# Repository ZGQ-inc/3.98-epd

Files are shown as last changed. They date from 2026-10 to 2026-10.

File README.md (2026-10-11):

# 3.98" BWRY 墨水屏随身伴侣 · Open E-Badge & Ita-Bag

<p align="center">
  3.98英寸 4色墨水屏外壳与随身工牌矢量图
</p>

<p align="center">
  <b>无需局域网 Wi-Fi · 手机 Chrome 蓝牙直连 · 100% 离线 PWA · Cloudflare Pages 免费一键托管</b><br>
  专为 3.98 英寸四色电子墨水屏打造的随身工牌、电子名片、兽聚痛卡与智能留言板开源软硬件全栈解决方案。
</p>

<p align="center">
  <a href="https://deploy.workers.cloudflare.com/?url=https://github.com/ZGQ-inc/3.98-epd">Deploy to Cloudflare Pages</a>
  
  
  
  
</p>

---

## 🌟 项目亮点 (Highlights)

1. **彻底告别 Wi-Fi 局域网依赖 (Zero Wi-Fi Needed)**:
   - 随身携带在展会、地铁、办公室或户外时，无需路由器局域网。
   - 打开手机或电脑 Chrome / Edge 浏览器访问部署好的 PWA 网页，点击“连接蓝牙”即可通过 Web Bluetooth API 直接与 3.98" 墨水屏握手直推。
2. **免费静态托管于 Cloudflare Pages**:
   - 纯前端无服务器架构（HTML5 + Canvas + Pure JS + Service Worker）。
   - 零成本全球 CDN 极速分发与自动权威 HTTPS（满足 Chromium WebBLE API 强制安全上下文要求）。
3. **100% 离线 PWA 支持 (Offline PWA)**:
   - 首次访问后，Service Worker 会将点阵字库生成器、二维码引擎和 4色微粒抖动算法缓存在本地。
   - 即使断网、飞行模式或深处地下场馆，依然能秒速打开并向墨水屏推送。
4. **四大随身定制工坊 (4 Built-in Studios)**:
   - 📇 **智能工牌 / 电子名片 (Smart E-Badge)**: 极客黑客、商务简约、同人展会等高对比度大字模板，内置零依赖纯离线二维码生成器。
   - 🎒 **兽聚痛卡 / 角色挂件 (Anime Ita-Bag Charm)**: 配合外壳双挂绳孔，相册选图、自由缩放/旋转、4色微粒抖动还原，个性台词题字。
   - 📝 **随身便签 / 留言板 (Memo & Checklist)**: 超大字号待办清单，方框复选框，磁吸/挂绳一目了然。
   - 🎨 **4色像素手绘画板 (BWRY Paint Canvas)**: 黑/白/红/黄 4色调色盘，画笔、矩形、圆形、题字、橡皮与撤销功能。
5. **极客级 3D 打印三明治外壳设计 (Optimized Enclosure)**:
   - **三明治三层坚固架构**: 前盖 + 中框 + 后盖独立分层，8 颗 M2 热熔铜螺母高强度锁合（前盖 4 颗 + 中框 4 颗）。
   - **防脱落滑动按键推钮**: 外露手按长度 1.5mm，加厚 7.0mm，四边 45° 倒角，内部防脱咬合卡块卡死后盖限位槽，杜绝脱落丢失。
   - **双挂绳孔**: 屏幕 FPC 一侧居中打 2 个穿绳孔（孔径 1.5mm，孔距 6mm），并带内部穿绳导引沉槽。
   - **前后双 NFC 贴片槽**: 中框正中心 + 后盖屏幕排线侧半边居中，适配 **NTAG216** (25mm 直径) 888 字节大容量贴片。
   - **4 颗强力吸附磁铁**: 后盖内壁预留 4 个 N52 钕铁硼磁铁沉孔（直径 6.0mm），可直接吸附在金属痛包或冰箱表面。

---

## 🗂️ 规范项目目录结构 (Repository Layout)

```text
.
├── README.md               # 项目主说明文档 (功能概览 / 快速编译与刷机指引)
├── BOM.md                  # 详尽硬件物料选型、采购单价与硬核避坑总结 (单一事实来源)
├── LICENSE                 # MIT 开源授权协议
├── .gitignore              # Git 忽略规则 (过滤 target/、编译缓存及临时文件)
│
├── hardware/               # 硬件与 3D 打印外壳工程
│   ├── README.md           # 3D 打印参数推荐与三明治全套组装指导
│   ├── enclosure_vector_mockup.svg # 外壳 1:1 矢量设计展示图
│   ├── 3d_models/          # 即用型 3D 打印 STL 模型与 OpenSCAD 源码
│   │   ├── case_front.stl  # 前框 (正面 6.9mm 窄边框，M2 铜螺母预埋孔)
│   │   ├── case_middle.stl # 中框 (双挂绳孔 1.5mm，正面 25mm NFC 槽，双 Type-C，'O'/`|` 开关标识)
│   │   ├── case_back.stl   # 标准后盖 (FPC 侧居中 25mm NFC 槽，4 个磁铁沉孔，电池防挤压圆角)
│   │   ├── case_back_logo.stl # 定制后盖 (带 "Made by ZGQ Inc." 凹刻文字)
│   │   ├── switch_cap.stl  # 防脱滑动推钮 (外露 1.5mm，卡紧后盖限位槽，4 道防滑齿)
│   │   ├── acrylic_template.stl # 91.0×64.0×1.5mm 亚克力视窗 1:1 划线切割模板
│   │   └── epd_case.scad   # 完整的 OpenSCAD 参数化建模源码
│   ├── scripts/
│   │   └── build_epd_case.py # Python 3D 网格生成脚本 (纯数学算法 + Delaunay 三角剖分)
│   └── fpc_adapter/        # 24-Pin 0.8mm 转 0.5mm 45° 转接板历史归档工程
│
├── cf_pages/               # 部署至 Cloudflare Pages 的 100% 离线独立 PWA 控制端
│   ├── README.md           # Cloudflare Pages 部署说明
│   ├── index.html          # 单页应用 (包含工牌、痛卡、便签、手绘 4 大工坊与 WebBLE 驱动)
│   ├── manifest.json       # PWA 应用配置清单
│   ├── sw.js               # Service Worker 离线缓存引擎 (v2.9)
│   ├── icon-192.svg        # 192x192 矢量图标
│   └── icon-512.svg        # 512x512 高清矢量图标
│
├── firmware/               # 预编译纯净固件与刷机指南
│   ├── README.md           # 详细环境配置与烧录步骤
│   └── epd-firmware.bin    # 预编译好的 1.76MB 裸机启动镜像 (即刷即用)
│
├── src/                    # Rust ESP-IDF 嵌入式主固件源码
│   ├── main.rs             # 系统启动入口、低功耗管理、任务并发调度
│   ├── ble/                # BLE 5.0 GATT 服务定义、流式点阵直推与无刷新预设协议
│   ├── display/            # 2bpp 硬件显存、无闪烁局刷与汉字字库渲染引擎
│   ├── storage/            # 1.5MB SPIFFS 效果库存储管理与物理配额统计
│   ├── modes/              # 工牌、痛卡、时钟、天气与便签模式逻辑
│   ├── power/              # 电源管理、电池电压 ADC 采样与休眠控制
│   ├── web/                # 内嵌轻量级 HTTP Web 服务器与 REST API
│   └── wifi/               # Wi-Fi 局域网通信与 AP 自动配网
│
├── web_assets/             # 编译期内嵌至固件的本地 Web 控制台静态资源
│   ├── index.html          # 局域网控制台 (已支持一键自定义配置您的专属 PWA 网址)
│   ├── index.html.gz       # 极速传输的 Gzip 压缩包
│   └── pwa.html            # 设备内置备用 PWA 页面
│
├── Cargo.toml              # Rust 项目依赖声明 (已配置 strip 自动剥离符号)
├── partitions.csv          # ESP32-C3 4MB Flash 分区表 (2MB App + 1.5MB SPIFFS 效果库)
└── sdkconfig.defaults      # ESP-IDF 系统底层配置 (启用蓝牙射频共存与蓝牙 5.0)
```

---

## 📋 硬件物料清单 (BOM)

关于器件的具体选型背景（**20~25 元华为生态四色墨水屏手机壳尾货捡漏实录**、高压驱动电压避坑、**663032 750mAh 锂电池**选型、**三明治 8 颗 M2 铜螺母锁固**及 NTAG216 智能名片细节），请直接参阅独立的硬件物料清单文档：

👉 **[硬件物料选型与采购清单 (BOM.md)](BOM.md)**

---

## 💻 固件编译与刷机指引 (Compilation & Flashing)

本项目主固件基于 **Rust ESP-IDF** 体系打造，针对 **ESP32-C3 (RISC-V 32位架构)** 进行了极致汇编与内存优化。

### 1. 为什么未剥离的 ELF 文件会有 20MB+？
在 `target/.../release/` 下生成的 `epd-firmware` 文件是标准的 RISC-V ELF 格式，包含了大量的 **DWARF 调试符号表**（`.debug_info`、`.debug_line`、函数符号与源码行号映射等，用于 GDB/LLDB 断点调试）。  
我们已在 `Cargo.toml` 中配置了 `debug = 0` 与 `strip = true`：
```toml
[profile.release]
opt-level = "z"
lto = "fat"
panic = "abort"
debug = 0
strip = true
```
真正烧录进单片机 Flash 的纯二进制镜像（.bin 文件）仅为 **1,764,592 字节（约 1.68 MB）**，完全适配 ESP32-C3 4MB Flash 的 **2MB 固件分区**（占用率 84.14%）。

---

### 2. 编译环境准备 (Prerequisites)

1. **安装 Rust 工具链**:
   ```bash
   curl --proto '=https' --tlsv1.2 -sSf https://sh.rustup.rs | sh
   ```
2. **安装 ESP32-C3 RISC-V 交叉编译器与烧录工具**:
   ```bash
   cargo install espup
   espup install
   cargo install espflash
   ```
3. **加载 ESP 编译环境变量**:
   - **Windows PowerShell**:
     ```powershell
     . $HOME/export-esp.ps1
     ```
   - **Linux / macOS**:
     ```bash
     source ~/export-esp.sh
     ```

---

### 3. 一键编译与固件导出

在项目根目录下执行：
```bash
# 1. 编译 release 生产模式固件
cargo +esp build --release

# 2. 将 ELF 可执行文件剥离并保存为单片机纯二进制镜像 (.bin)
espflash save-image --chip esp32c3 target/riscv32imc-esp-espidf/release/epd-firmware firmware/epd-firmware.bin
```

---

### 4. 烧录到设备 (Flash to ESP32-C3)

将 ESP32-C3 SuperMini 通过 Type-C 数据线连接至电脑：

#### 方式一：使用 `espflash` 自动烧录（最推荐）
```bash
# 自动探测串口并烧录
espflash flash --release

# 或指定具体串口号（例如 Windows 上的 COM17，Linux 上的 /dev/ttyUSB0）
espflash flash --port COM17 --release
```

#### 方式二：免编译直接烧录预编译镜像 (.bin)
仓库已在 `firmware/epd-firmware.bin` 预先提供了最新编译好的裸机固件。您可以使用 Python 的 `esptool.py` 直接刷入：
```bash
esptool.py --chip esp32c3 -p <PORT> -b 460800 write_flash 0x20000 firmware/epd-firmware.bin
```

---

### 5. Flash 分区表规划 (Partitions Layout)

4MB Flash 布局严格按照 `partitions.csv` 划分：

| 分区名 | 类型 | 子类型 | 偏移地址 | 大小 | 作用说明 |
| :--- | :--- | :--- | :--- | :--- | :--- |
| `nvs` | data | nvs | `0x9000` | 24 KB | 存储 Wi-Fi 凭据、蓝牙名称与模式持久配置 |
| `phy_init` | data | phy | `0x11000` | 4 KB | 射频初始化与天线校准数据 |
| `factory` | app | factory | `0x20000` | 2048 KB (2.0 MB) | Rust ESP-IDF 主固件代码段 (当前占用约 84%) |
| `font` | data | 0x01 | `0x220000` | 288 KB | Flash MMU 零内存占用标准点阵中文字库 |
| `storage` | data | spiffs | `0x268000` | 1632 KB (~1.6 MB) | 单片机内置 SPIFFS 效果库 (真实物理存储) |

---

## 🚀 1 分钟一键部署至 Cloudflare Pages

1. Fork 本仓库到你自己的 GitHub 账号；
2. 登录 [Cloudflare Dashboard](https://dash.cloudflare.com/)，点击 **Workers & Pages** -> **Create application** -> **Pages** -> **Connect to Git**；
3. 选择该仓库，配置构建参数：
   - **Framework preset**: `None`
   - **Build command**: *(留空)*
   - **Build output directory**: `cf_pages`
4. 点击 **Save and Deploy**，30 秒后即可获得免费的全球 CDN HTTPS 域名（例如: `https://my-epd-badge.pages.dev`）！
5. 在手机或电脑 Chrome / Edge 浏览器打开该网址，点击“连接蓝牙”即可开箱即用。

---

## 📄 开源许可证 (License)

本项目采用 [MIT 许可证](LICENSE) 开源，欢迎自由构建、修改、二次开发与商业/非商业分享！

> 💡 **关于版权与署名说明**：  
> 版权声明中的 `ZGQ Inc.` 仅为作者个人昵称（Author Handle）。本项目全栈源代码、固件、前端 PWA 及相关硬件工程文件均遵循宽松的 **MIT 许可证** 开放授权，任何人均可在遵守并保留 MIT 许可证声明的前提下自由使用、修改与衍生开发。

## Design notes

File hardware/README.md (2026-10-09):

# 3D 打印外壳与硬件结构设计指南 (Hardware & Enclosure)

本目录包含 3.98 英寸四色电子墨水屏随身工牌 & 兽聚痛卡的全部 3D 打印外壳 STL 模型、OpenSCAD 参数化源码、Python 网格构建脚本以及 FPC 屏幕转接板工程。

---

## 📁 目录结构说明

```text
hardware/
├── BOM.md                  -> 详细元器件选型与物料采购清单
├── enclosure_vector_mockup.svg -> 外壳 1:1 矢量结构展示图
├── 3d_models/              -> 3D 打印即用型 STL 文件与 OpenSCAD 源码
│   ├── case_front.stl      -> 前框 (正面 6.9mm 窄边框，M2 铜螺母预埋孔)
│   ├── case_middle.stl     -> 中框主体 (FPC侧与开关对面底壁双向双挂绳孔 1.5mm，支持横屏/竖屏挂绳，正面 25mm NFC 槽，双 Type-C 开孔，开关滑轨与 'O'/`|` 标识)
│   ├── case_back.stl       -> 标准后盖 (FPC 侧居中 25mm NFC 槽，4 个磁铁沉孔，电池防挤压 R7 圆角)
│   ├── case_back_logo.stl  -> 定制后盖 (带 "Made by ZGQ Inc." 激光/成型凹刻文字)
│   ├── switch_cap.stl      -> 防脱落滑动按键推钮 (外露 1.5mm，防脱咬合卡爪，4 道防滑齿)
│   ├── acrylic_template.stl-> 91.0 × 64.0 × 1.5 mm 亚克力视窗 1:1 划线/切割辅助治具
│   └── epd_case.scad       -> 完整的 OpenSCAD 参数化建模源码
├── scripts/
│   └── build_epd_case.py   -> Python 3D 网格生成脚本 (纯数学算法 + Delaunay 三角剖分)
└── fpc_adapter/            -> 24-Pin 0.8mm 转 0.5mm 45° 转接板工程（已作废归档，现采用 OSHWHub flamj0 高压驱动板）
```

> ⚠️ **关于转接板作废归档说明**：  
> 原自制 45° FPC 转接排线工程仅完成物理引脚间距转换（0.8mm 转 0.5mm），而 3.98" 四色屏（`SE0398NZ07`）需要高达 +22V / -20V / +15V 物理驱动偏压，普通驱动板无法正常工作。因此自制转接板已作废归档，硬件推荐采用立创开源硬件平台 [@flamj0 的墨水屏 FPC 转接板](https://oshwhub.com/flamj0/mo-shui-ping-fpc-zhuan-jie-ban)。

---

## 🖨️ 3D 打印参数推荐

| 打印部件 | 推荐层高 | 填充率 | 支撑设置 | 推荐材料 | 打印建议与方向 |
| :--- | :---: | :---: | :---: | :---: | :--- |
| **`case_front.stl`** | 0.12 - 0.16 mm | 100% | 无需支撑 | PETG / PLA+ / 树脂 | 外表面朝下贴紧热床，使用纹理 PEI 板可获得磨砂质感 |
| **`case_middle.stl`**| 0.12 - 0.16 mm | 100% | 局部轻微树状支撑 | PETG / ABS / 树脂 | 底部朝下平放，Type-C 开孔处开启少量支撑即可 |
| **`case_back.stl`**  | 0.12 - 0.16 mm | 100% | 无需支撑 | PETG / PLA+ / 树脂 | 外背面朝下贴紧热床 |
| **`switch_cap.stl`** | 0.08 - 0.12 mm | 100% | 无需支撑 | PETG / 高韧性光敏树脂 | 竖直或侧放打印，确保拔销孔尺寸精确 |

---

## 🔧 装配步骤示意

1. **热熔螺母安装**:
   - 取 4 颗 M2 铜螺母（外径 3.2mm，高 3.0~3.5mm），使用电烙铁压头对准 `case_front.stl` 背面的 4 个定位孔，轻压热熔至与塑料表面平齐。
2. **安装保护视窗与墨水屏**:
   - 依据 `acrylic_template.stl` 切割好 91.0×64.0×1.5mm 的透明亚克力板，嵌入口框内；
   - 将 3.98" 墨水屏正面四周贴好 0.3mm 超薄双面胶，居中粘合在前框背面。
3. **中框组件安装**:
   - 将微型滑动开关卡入中框顶部开关位，同时将 3D 打印推钮 `switch_cap.stl` 套在开关手柄上；
   - 固定 ESP32-C3 SuperMini 与 TP4056 充电板，确保两个 Type-C 接口分别居中露出；
   - 焊接开关引脚（控制电池正极切断/导通），连接电池与主控电源轨。
4. **NFC 贴片与磁铁装配**:
   - 中框正面中心凹槽粘贴第 1 枚 NTAG216 NFC 贴片；
   - 后盖排线侧半边中心凹槽粘贴第 2 枚抗金属 NTAG216 NFC 贴片；
   - 后盖内侧 4 个沉孔内分别压入 4 颗 N52 强力磁铁（6.0×1.2mm），可用少量 UV 胶或瞬干胶固定。
5. **合盖紧固**:
   - 将后盖对齐中框，确保滑动推钮防脱卡块嵌入后盖限位槽内；
   - 从后盖正面旋入 4 颗 M2×8mm 沉头机械螺丝并锁紧。

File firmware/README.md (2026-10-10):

# 固件烧录与编译指南 (Firmware Compilation & Flashing Guide)

本固件基于 **Rust ESP-IDF** 体系打造，专为 **ESP32-C3** (RISC-V 32位架构) 设计，实现了 4色墨水屏硬件显存管理、Web Bluetooth (WebBLE) 蓝牙直推、Wi-Fi 局域网控制台与低功耗多模式共存。

---

## 🛠️ 编译环境配置 (Prerequisites)

1. **安装 Rust 工具链**:
   ```bash
   curl --proto '=https' --tlsv1.2 -sSf https://sh.rustup.rs | sh
   ```
2. **安装 ESP32-C3 RISC-V 交叉编译器与 espflash 工具**:
   ```bash
   cargo install espup
   espup install
   cargo install espflash
   ```
3. **加载 ESP 环境变量**:
   - **Windows PowerShell**:
     ```powershell
     . $HOME/export-esp.ps1
     ```
   - **Linux / macOS**:
     ```bash
     source ~/export-esp.sh
     ```

---

## 📦 固件编译与剥离 (Build & Strip)

项目 `Cargo.toml` 已经内置了符号剥离配置（`debug = 0`, `strip = true`, `lto = "fat"`）：

```bash
# 1. 在项目根目录执行 release 编译
cargo +esp build --release

# 2. 将 ELF 可执行文件提取为纯净裸机固件镜像 (.bin)
espflash save-image --chip esp32c3 target/riscv32imc-esp-espidf/release/epd-firmware firmware/epd-firmware.bin
```

> **💡 ELF 与 BIN 的体积说明**:
> - `target/.../release/epd-firmware` 是未提取的 ELF 格式，早期包含 DWARF 调试符号时可达 20MB+（现经 `strip = true` 优化后约 3MB）；
> - 真正通过 `espflash save-image` 或 `espflash flash` 烧录进 ESP32-C3 Flash 的裸机二进制固件（`.bin`）仅为 **1,764,592 字节（约 1.68 MB）**，完全适配 2MB 固件分区。

---

## ⚡ 一键烧录到设备 (Flash)

### 方式一：使用 `espflash` 自动烧录 (最推荐)
将 ESP32-C3 SuperMini 通过 Type-C 数据线连接至电脑（设备管理器中查看端口号，例如 Windows 上的 `COMx` 或 Linux 上的 `/dev/ttyUSB0`）：
```bash
# 自动检测串口并烧录
espflash flash --release

# 或指定具体串口（请将 COM17 替换为你的实际串口号）
espflash flash --port COM17 --release
```

### 方式二：免编译直接使用 `esptool.py` 刷入预打包固件
本目录已预先提供构建好的 `epd-firmware.bin` (1.76MB)：
```bash
esptool.py --chip esp32c3 -p <PORT> -b 460800 write_flash 0x20000 firmware/epd-firmware.bin
```

---

## 🧭 Flash 分区表规划 (Partitions Table)

4MB Flash 布局严格遵循项目根目录下的 `partitions.csv`：

| 分区名 (Name) | 类型 (Type) | 子类型 (SubType) | 偏移地址 (Offset) | 分区大小 (Size) | 作用说明 |
| :--- | :--- | :--- | :--- | :--- | :--- |
| `nvs` | data | nvs | `0x9000` | 24 KB (`0x6000`) | 存储 Wi-Fi 凭据、蓝牙设备名与模式配置 |
| `phy_init` | data | phy | `0x11000` | 4 KB (`0x1000`) | 射频初始化校准数据 |
| `factory` | app | factory | `0x20000` | 2048 KB (`0x200000`, 2.0MB) | Rust ESP-IDF 完整主固件镜像 (当前约占 84%) |
| `font` | data | 0x01 | `0x220000` | 288 KB (`0x48000`) | Flash MMU 零内存占用标准点阵中文字库 |
| `storage` | data | spiffs | `0x268000` | 1632 KB (`0x198000`, ~1.6MB)| 单片机内置 SPIFFS 效果库 (真实物理存储) |

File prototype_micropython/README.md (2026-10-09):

# 3.98" BWRY 墨水屏 MicroPython 原型验证 Demo (Prototype)

本目录包含了项目初期用于验证 3.98 英寸四色墨水屏（SSD1683 控制器，768×552 分辨率）硬件管脚、SPI 通信、微粒抖动算法与刷新波形的核心 MicroPython 驱动与测试例程。

---

## 📁 文件清单

- **`epd3in98.py`**:
  - 3.98 英寸 4 色电子墨水屏 (BWRY) 的 MicroPython 底层驱动库。
  - 封装了 SSD1683 的 SPI 初始化序列、寄存器控制、2bpp (2-bit per pixel) 显存管理、全刷/局刷控制及低功耗休眠指令。
- **`demo.py`**:
  - 基础硬件与图像测试脚本。
  - 演示了四色基础几何图形绘制、文字排版题字以及将 RAW 二进制图像推送至墨水屏物理刷新的完整流程。
- **`convert_image.py`**:
  - PC 端图片格式转换与 4 色 Floyd-Steinberg 误差扩散抖动算法脚本。
  - 可将任意格式的 JPG/PNG 图片缩放为 768×552 并转换为黑/白/红/黄 4 色 2bpp 原始显存二进制文件（`.raw`）。
- **`avatar.raw`**:
  - 预生成的 768×552 4 色测试图片二进制数据样本（可直接由 `demo.py` 读取刷屏）。
- **`SE0398NZ07_MicroPython.zip`**:
  - 原始完整备份压缩包（含厂家技术参考、引脚对照图与初期测试工程）。

---

## 🚀 快速测试方法 (MicroPython)

1. 在开发板（如 ESP32-C3）上刷入标准 MicroPython 固件；
2. 使用 Thonny IDE 或 `mpremote` / `ampy` 将 `epd3in98.py`、`demo.py` 和 `avatar.raw` 上传到开发板根目录；
3. 根据硬件接线修改 `demo.py` 中的 GPIO 引脚分配（SCK, MOSI, CS, DC, RST, BUSY）；
4. 运行 `demo.py`，墨水屏即可完成物理颗粒沉淀全彩刷新。

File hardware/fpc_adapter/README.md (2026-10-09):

# 【作废存档 · ARCHIVED】24-Pin 0.8mm 焊接 转 0.5mm 45° 仿形转接排线工程

> ⚠️ **作废与归档声明 (DEPRECATION & ARCHIVE NOTICE)**：  
> 本目录下的 24-Pin 0.8mm 转 0.5mm 45° 仿形转接排线工程已正式**作废并封存归档**。
>
> **原因说明**：  
> 如原型文章（[25元捡漏3.98寸四色墨水屏！MicroPython 驱动与 FPC 转接避坑实录 · ID: e398nz](https://zgqinc.gq/posts/e398nz/)）中所述，3.98 英寸四色墨水屏（`SE0398NZ07-FNG-A0`）采用高密度 BWRY 彩色电泳微胶囊，其翻转电场需要极高的物理高压驱动（`VGH` +22V / `VGL` -20V / `VSH` +15V）。市售普通通用 24P 黑白屏驱动板由于升压回路电感与元器件耐压不足，无法拉升至所需阈值，会导致 BUSY 信号永久忙死锁或刷屏缺色淡色。
>
> **现行推荐替代方案**：  
> 本项目现已全面改用立创开源硬件平台（OSHWHub）成熟开源项目：  
> **[墨水屏 FPC 转接板 (OSHWHub @flamj0)](https://oshwhub.com/flamj0/mo-shui-ping-fpc-zhuan-jie-ban)**  
> 该转接板自带足额储能电感与高耐压升压驱动回路，可直接将 3.98" 裸屏安全稳定连接至主控。
>
> 本目录完整保留历史 KiCad 版图源码、Gerber 打样压缩包与 EasyEDA 导入工程，仅供技术研究、引脚对照与历史归档参考，**新制作请勿再打样此转接板**。

---

## 🛠️ 历史设计特性归档 (Historical Design Archive)

1. **45° 仿形外形 (Contour Outline)**：
   - 移除原先直角两侧多余无走线的死基材，外框完全沿 45° 扇出走线平滑收拢，轻量美观。
2. **插舌与金手指精密适配 (J_ZIF)**：
   - 插舌宽度严格控制在 **12.50 mm**，前端带有 **0.3 mm × 45° 导向倒角**，插拔顺畅不卡壳。
   - 金手指长度加长至 **3.20 mm**（原 1.8mm），确保在任意 0.5mm ZIF 翻盖插座中弹片均能可靠接触。
   - 采用整排开窗（Gang Mask Opening，无开窗桥），彻底解决 0.2mm 窄间隙覆盖膜起翘与毛刺问题。
3. **消除冗余底层铜皮**：
   - 完全清理了原先底层未连接走线的 24 个冗余焊盘，避免热应力翘曲及寄生耦合。
4. **PI 补强层定义 (User.1 / Stiffener)**：
   - **插舌背面**：`12.50 mm × 3.50 mm` PI 补强片（建议选择 0.15~0.20mm PI，加上 0.11mm 板厚总计约 0.3mm，完美卡紧）。
   - **焊接端背面**：`20.40 mm × 3.50 mm` 耐热 PI 补强片，方便手工电烙铁焊接与支撑。
5. **极客风格丝印 (SilkScreen)**：
   - 正面标注 `[ ZGQ Inc. ]`、`EPD 24P: SOLDER > ZIF`、`3.98" SCREEN ADAPTER`。
   - 醒目标注两端 `1`、`24` 脚位与常用引脚功能标识，且全部严格位于板框安全间距内。
6. **嘉立创双面 FPC 0元体验券原生兼容**：
   - 导出文件包含完整的顶层与底层层叠定义，嘉立创自动识别为双面板，完美享受官方“双面 FPC 免费券（含 1 种 PI 补强免单）”。

---

## 📐 24-Pin 引脚网络映射参考表 (1:1 直连)

| Pin # | 引脚名称 | 功能说明 | 屏幕端 (0.8mm) | 驱动板端 (0.5mm) |
| :---: | :---: | :---: | :---: | :---: |
| **1** | GDR | N沟道MOS驱动 (Boost Gate) | Pad 1 | Pin 1 |
| **2** | RESE | 电流采样反馈电阻端 | Pad 2 | Pin 2 |
| **3** | VSH2 | 升压正高压 2 (约 +15V) | Pad 3 | Pin 3 |
| **4** | NC (PREVGH) | 预留升压测试脚 (内部悬空) | Pad 4 | Pin 4 |
| **5** | NC (PREVGL) | 预留升压测试脚 (内部悬空) | Pad 5 | Pin 5 |
| **6** | NC (TSCL) | 触控时钟 (本屏无触控) | Pad 6 | Pin 6 |
| **7** | NC (TSDA) | 触控数据 (本屏无触控) | Pad 7 | Pin 7 |
| **8** | BS | 通讯模式选择 (拉低默认 SPI) | Pad 8 | Pin 8 |
| **9** | BUSY | 墨水屏忙状态指示 (低电平忙) | Pad 9 | Pin 9 |
| **10** | RST | 硬件复位信号 (低电平复位) | Pad 10 | Pin 10 |
| **11** | DC | 数据/命令控制脚 (高:数据, 低:命令)| Pad 11 | Pin 11 |
| **12** | CS | 片选信号 (低电平有效) | Pad 12 | Pin 12 |
| **13** | SCL / CLK | SPI 同步时钟信号 | Pad 13 | Pin 13 |
| **14** | SDA / DIN | SPI 串行数据输入信号 | Pad 14 | Pin 14 |
| **15** | VDDIO | 逻辑供电 (3.3V) | Pad 15 | Pin 15 |
| **16** | VCI / VDD | 模拟主供电 (3.3V) | Pad 16 | Pin 16 |
| **17** | VSS / GND | 系统参考地 | Pad 17 | Pin 17 |
| **18** | VDD | 核心稳压电容引脚 | Pad 18 | Pin 18 |
| **19** | VPP | OTP 烧录高压供电 (悬空/接电容) | Pad 19 | Pin 19 |
| **20** | VCOM | 屏幕公共极驱动电压 | Pad 20 | Pin 20 |
| **21** | VGL | 负偏压驱动电压 (约 -20V) | Pad 21 | Pin 21 |
| **22** | VGH | 正偏压驱动电压 (约 +22V) | Pad 22 | Pin 22 |
| **23** | VSL | 负驱动参考电压 | Pad 23 | Pin 23 |
| **24** | VSH1 | 正驱动参考电压 1 (约 +15V) | Pad 24 | Pin 24 |

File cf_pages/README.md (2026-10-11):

# 3.98" BWRY E-Paper Open Smart Badge & Ita-Bag (开源墨水屏随身伴侣)

> **Zero Wi-Fi Required** · **100% Client-Side Offline PWA** · **Web Bluetooth (WebBLE) Direct Drive** · **One-Click Deploy to Cloudflare Pages**

Deploy to Cloudflare Pages (https://deploy.workers.cloudflare.com/?url=https://github.com/ZGQ-inc/3.98-epd)




---

## 🌟 项目亮点 (Highlights)

1. **彻底告别 Wi-Fi 依赖 (No Wi-Fi Needed)**:
   - 随身携带在兽聚、地铁、办公室或野外时，无需路由器局域网。
   - 打开手机或电脑 Chrome / Edge 浏览器访问本 PWA 网页，点击“连接蓝牙”即可通过 Web Bluetooth API 直接与 3.98" 墨水屏握手通信。
2. **免费静态托管于 Cloudflare Pages**:
   - 纯前端静态架构（HTML5 + Canvas + Pure JS + Service Worker）。
   - 无需任何后端服务器、Docker 或数据库，零成本全球 CDN 极速分发与自动 HTTPS（WebBLE API 强制要求 HTTPS）。
3. **100% 离线 PWA 支持 (Offline PWA)**:
   - 首次访问后，Service Worker 会将所有点阵字库生成器、RFC-Compliant 二维码引擎和 4色抖动算法缓存在本地。
   - 即使断网、飞行模式或深处兽聚地下场馆，依然能秒速打开并向墨水屏推送。
4. **四大随身定制工坊 (4 Built-in Studios)**:
   - 📇 **智能工牌 / 电子名片定制 (Smart E-Badge)**: 极客黑客、商务简约、兽聚同人、展会工作证 4 套高对比度大字模板，内置零依赖纯离线二维码生成器。
   - 🎒 **兽聚痛卡 / 角色挂件 (Anime Ita-Bag Charm)**: 配合 3D 打印外壳的双挂绳孔设计，相册选图、自由缩放/旋转、4色微粒抖动还原，个性台词题字。
   - 📝 **随身便签 / 冰箱贴 (Memo & Checklist)**: 32px 超大字号待办清单，方框复选框，磁吸/挂绳一目了然。
   - 🎨 **4色像素手绘画板 (BWRY Paint Canvas)**: 黑/白/红/黄 4色调色盘，画笔、矩形、圆形、题字、橡皮与撤销功能。
5. **多设备记忆与切换 (Multi-Device Support)**:
   - 自动记忆多个已配对的墨水屏胸牌与痛包挂饰，支持自定义备注别名（例如“工作胸牌”、“痛包立绘挂饰”、“厨房留言板”），一键重连。
6. **蓝牙隔空配网 (BLE Air Provisioning)**:
   - 如果用户后续需要连接 Wi-Fi（例如用于 Home Assistant 联动、天气看板、NTP 时钟），无需连接难用的 AP 热点，直接在蓝牙控制台中输入 SSID 和密码一键隔空写入。

---

## 🚀 1分钟部署到 Cloudflare Pages (Deploy Guide)

### 方式一：一键自动部署 (Recommended)
1. 将本仓库 `cf_pages/` 目录推送到你自己的 GitHub 仓库。
2. 登录 [Cloudflare Dashboard](https://dash.cloudflare.com/)，进入 **Workers & Pages** -> **Create application** -> **Pages** -> **Connect to Git**。
3. 选择你的仓库，配置如下：
   - **Framework preset**: `None`
   - **Build command**: *(留空)*
   - **Build output directory**: `.` (或填写 `cf_pages`)
4. 点击 **Save and Deploy**，30 秒内即可获得专属于你的全球 HTTPS 地址（如 `https://my-epd-badge.pages.dev`）！

### 方式二：Cloudflare Wrangler CLI 部署
```bash
npm install -g wrangler
cd cf_pages
wrangler pages deploy . --project-name=epd-badge
```

---

## 📱 手机与电脑蓝牙直连要求 (Browser Compatibility)

| 平台 / 操作系统 | 推荐浏览器 | Web Bluetooth 支持情况 |
| :--- | :--- | :--- |
| **Android** | Google Chrome / Edge / Opera | ✅ 开箱即用 (原生支持 WebBLE) |
| **Windows / macOS** | Google Chrome / Microsoft Edge | ✅ 开箱即用 (需系统支持蓝牙 4.0+) |
| **Linux** | Google Chrome / Chromium | ✅ 需开启 `chrome://flags/#enable-web-bluetooth` |

---

## 📐 硬件规格参数 (Hardware Specifications)

- **显示面板**: 3.98 英寸超高清 4 色电子墨水屏 (BWRY: 黑/白/红/黄)
- **分辨率**: 768 × 552 像素 (1:1 点对点 2bpp 硬件显存，整屏 105,984 字节)
- **主控芯片**: ESP32-C3 SuperMini (RISC-V 160MHz, BLE 5.0 + Wi-Fi 802.11b/g/n)
- **刷新速度**: ~16 秒物理全色阶颗粒沉淀刷新，断电永久保持画面不耗电
- **结构设计**:
  - 外壳左上方配备 **双挂绳孔** (间距 6.0mm，孔径 1.5mm)，便于穿过挂绳作为胸牌或钥匙扣。
  - 内置 **前后双 NFC 贴片凹槽** (中框正中心 + 屏幕排线侧背面中心，直径 25.5mm)，可贴手机触碰感应标签。
  - 防脱落拨动开关推扭设计 (防掉防脱手感优化)。

---

## 📡 蓝牙 GATT 协议接口规范 (BLE Specification)

- **Service UUID**: `000000ff-0000-1000-8000-00805f9b34fb`
- **RX Characteristic (Write Without Response)**: `0000ff01-0000-1000-8000-00805f9b34fb`
  - 用于流式接收 2bpp 105,984 字节点阵（单包建议 240 字节）或 JSON/文本控制指令。
- **TX Characteristic (Notify / Read)**: `0000ff02-0000-1000-8000-00805f9b34fb`
  - 用于向网页回报墨水屏当前电量、刷新进度、IP 地址与状态信息。

### 控制指令速查：
- `refresh` : 触发墨水屏 16s 物理全刷新
- `mode:<mode_name>` : 切换预设场景（如 `demo`, `memo`, `fridge_board`, `weather` 等）
- `wireless:<mode>` : 切换射频模式（`auto`, `ble_only`, `wifi_only`, `dual`）
- `{"cmd":"wifi_setup","ssid":"...","pass":"..."}` : 隔空配置 Wi-Fi 路由器信息

---

## 📄 开源许可证 (License)

本项目采用 [MIT 许可证](https://github.com/ZGQ-inc/3.98-epd/blob/main/LICENSE) 开源。

> 💡 **关于版权与署名说明**：  
> `ZGQ Inc.` 仅为作者个人昵称（Author Handle）。本项目前端 PWA 代码、UI 及模型均以宽松的 MIT License 开放授权，任何人均可在遵守 MIT 协议的前提下自由学习、修改、二次开发与商业/非商业分享。

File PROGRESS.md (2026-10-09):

# EPD Smart Display Firmware (Rust) — 实施进度记录 (PROGRESS.md)

> 设备：ESP32-C3 SuperMini + 3.98" 4色墨水屏（SE0398NZ07-FNG-A0/A1，768×552，4色BWRY）  
> 目标端口：COM17 (4MB SPI Flash)  
> 当前版本：v2.0  
> 最新更新时间：2026-10-07 01:28

---

## 阶段推进状态总览

| 阶段 | 任务目标 | 状态 | 交付文件与技术要点 |
|---|---|---|---|
| **Phase 0** | 工具链探测、分区表规划与工程基建 | **已完成 (DONE)** | `partitions.csv`, `Cargo.toml`, `sdkconfig.defaults`, `.cargo/config.toml`, `build.rs` |
| **Phase 1** | 768×552 4色墨水屏底层驱动与显存渲染核 | **已完成 (DONE)** | `src/display/color.rs`, `src/display/framebuffer.rs`, `src/display/driver.rs`, `src/display/font.rs`, `src/display/mod.rs` |
| **Phase 2** | WiFi网络管理 (AP/STA/Captive Portal)、HTTPD服务与REST API | **已完成 (DONE)** | `src/wifi/mod.rs`, `src/wifi/captive.rs`, `src/web/mod.rs`, `src/web/api.rs`, `src/config/mod.rs` |
| **Phase 3** | 17 项全场景内容模式渲染引擎 | **已完成 (DONE)** | `src/modes/mod.rs` (Memo, Calendar, Weather, FridgeBoard, Countdown, Habit, LifeBar 等) |
| **Phase 4** | 调度器、休眠/心跳模式与 Home Assistant MQTT 集成 | **已完成 (DONE)** | `src/power/mod.rs`, `src/mqtt/mod.rs`, `src/scheduler/mod.rs` |
| **Phase 5** | Material Web 控制台与 Fabric.js Canvas 布局编辑器 | **已交付 (DONE)** | `web_assets/index.html`：768×552 自由拖拽画布排版 Studio 与全功能配置面板 |
| **Phase 6** | 系统联调、固件构建与实机全链路运行验证 | **已交付并通过实机验证 (PASSED & VERIFIED)** | Release 固件成功构建，已烧录至 COM17，SoftAP `EPD-Display-A00D` 现场广播正常，WebUI/DNS 就绪 |
| **Phase 7** | 内存/体积优化、断电智能免刷新与 WebUI 推送全闭环 | **全部完成并通过物理实机验证 (PASSED & VERIFIED)** | 可用堆内存提升至 75KB+；固件裁剪至 1.39MB；CRC32 断电状态记忆免闪烁；Web 端画布与模式切换全链路打通 |

---

## 详细里程碑记录

### [2026-10-07 01:12] Phase 0：基础工程与构建配置交付
1. 探测本地工具链：确认 `rustc +esp` (nightly), `espflash 4.6.0`, `ldproxy`, `libclang.dll` 完好就绪。
2. 验证 COM17 物理板载连接：成功识别 `esp32c3 (revision v0.4)`，4MB Flash，MAC `14:63:93:6e:a0:0c`。
3. 创建 4MB Flash 自定义分区表 `partitions.csv`（nvs, otadata, phy_init, ota_0 (1.5MB), ota_1 (1.5MB), storage/spiffs (896KB)）。
4. 创建 `sdkconfig.defaults`：配置 4MB Flash、USB-Serial/JTAG 默认控制台、WiFi SoftAP、mbedTLS 堆栈削减。
5. 配置 `.cargo/config.toml`：重定向构建产物到 `C:\esp_b\epd`（防 Windows 路径超长），配置 `rust-lld.exe` 主机链接器与 `xwin` 库路径。

### [2026-10-07 01:14] Phase 1：4色墨水屏驱动与 103.5KB 显存交付
1. **`src/display/color.rs`**：定义 SE0398NZ07 4 色枚举（BWRY: Black=00, White=01, Yellow=10, Red=11），实现 `embedded_graphics::pixelcolor::PixelColor`。
2. **`src/display/framebuffer.rs`**：显存移至编译期 `.bss` 静态区（`EPD_STATIC_BUFFER`），105,984 字节 / 103.5 KB，**0 字节动态堆开销**，彻底规避运行时内存碎片与 OOM；为 `BwryColor` 实现 `DrawTarget`；实现毫秒级快速单色清屏与 2-bit 点阵零开销 blit。
3. **`src/display/driver.rs`**：完整移植 A0/A1 物理交错扫描线地址映射（CMD `0x83` + `0x10`），配置 8MHz 硬件 SPI（SCK=4, MOSI=6, CS=7, DC=1, RST=2, BUSY=10），精准匹配 16 秒物理波形刷新与深度休眠序列。
4. **`src/display/font.rs`**：封装多规格等宽字体与文字居中排版工具。

### [2026-10-07 01:15] Phase 2：网络、配网与嵌入式 HTTPD 交付
1. **`src/config/mod.rs`**：NVS 键值对持久化引擎，使用 `get_blob` / `set_blob` 支持序列化/反序列化 WiFi 凭据、MQTT 与展示偏好。
2. **`src/wifi/captive.rs`**：在 UDP 53 端口自建轻量 DNS 重定向服务器，实现手机连上 SoftAP 自动弹出 Captive Portal 配网页面。
3. **`src/wifi/mod.rs`**：WiFi 状态机管理（未配网或连不上时自动开启 `EPD-Display-XXXXXX` AP，已配网自动连 STA），锁定 `heapless 0.9` 统一接口。
4. **`src/web/api.rs`**：REST API 数据结构（系统状态、WiFi 配网请求、统一响应体）。
5. **`src/web/mod.rs`**：基于 `EspHttpServer` 提供 REST 接口与内置自适应 Material Design 响应式控制台。
6. **`src/power/mod.rs`**：支持心跳省电模式与 RTC 定时 Deep Sleep。

### [2026-10-07 01:16] Phase 3 & Phase 4：17 种内容模式、MQTT 与调度引擎交付
1. **`src/modes/mod.rs`**：抽象 `DisplayMode` trait 与统一分发器，实现便签、日历、全维气象、冰箱贴布告板、倒计时、打卡热力图、人生进度条等 17 种场景模式。
2. **`src/mqtt/mod.rs`**：接入 Home Assistant 官方最新的 Device-Based MQTT Auto Discovery 规范，自动向 HA 注册电量传感器、刷新按钮与心跳休眠开关。
3. **`src/scheduler/mod.rs`**：多级后台定时调度器，协调气象轮询、午夜日历切换与心跳遥测。
4. **`src/main.rs`**：完整链路编排与外设启动。

### [2026-10-07 01:25] Phase 5：Web 控制台与 Fabric.js 768×552 Studio 交付
1. **`web_assets/index.html`**：实现基于 Fabric.js v6 的 768×552 物理点阵等比自由拖拽画布，支持文本、天气、日历、备忘等挂件自由排版与 4 色模拟。

### [2026-10-07 18:10] Hotspot WebUI 超时问题彻底根治与验证
1. **HTTP 协议报头优化**：
   - 为所有 HTTP 响应（包括主页 `/`、Captive Portal 302 重定向以及 `/api/*` REST 接口）严格注入 `Content-Length` 与 `Connection: close`。
   - 彻底解决了 HTTP/1.1 默认 Keep-Alive 模式下移动端与桌面端浏览器接收完数据后因缺少 EOF 标识而无限悬挂加载最终超时的严重问题。
2. **启动顺序调整**：
   - 将 `WebServer::start` 调整至 WiFi 启动后**立刻执行**（不再受耗时 16~40 秒的墨水屏全屏波形刷新阻塞），开机 1 秒内 HTTP 服务器即上线监听 80 端口。
3. **DNS Captive Portal RFC 规范兼容**：
   - 在 UDP 53 端口 DNS 回应中对 Question 边界做严格字节解析并清除 `ARCOUNT`，彻底解决各平台移动设备发送 EDNS0/OPT 附加段时 DNS 解析损坏被系统静默丢弃的问题。
### [2026-10-07 18:40] 基于成熟项目 mi-remote-esp32 完整重构强制门户（Captive Portal）与配网架构
1. **参考 mi-remote-esp32 成功实现重构**：
   - 采用同款经真机实测检验的 **「无网自动降级 AP + DNS 劫持强制弹窗 + 轻量 WebUI 提交 + NVS 持久化重启」** 架构。
   - `src/wifi/mod.rs`：显式调用 `wait_netif_up` 后，对 AP Netif 执行 `esp_netif_dhcps_stop` -> 绑定 `192.168.4.1` -> `esp_netif_dhcps_start` 完整 DHCP 生命周期，避免手机获取不到网关与 DNS。
   - `src/wifi/captive.rs`：精确实现 4KB 独立线程 UDP 53 DNS 欺骗响应，将所有 A 记录查询重定向至 `192.168.4.1`。
   - `src/web/mod.rs`：拦截系统专属探测路由（`/generate_204`、`/gen_204`、`/hotspot-detect.html`、`/ncsi.txt`、`/connecttest.txt` 等），统一直接下发 `web_assets/captive.html` 单页。使用 `Box::leak(Box::new(server))` 确保 HTTP 守护线程生命周期永久有效。
   - `src/wifi/mdns.rs`：新增基于局域网组播的 mDNS 响应器，连网后电脑或手机浏览器可直接通过 `http://epd-display.local` 免 IP 访问控制台。
### [2026-10-07 18:48] Wi-Fi 成功连网、C3 迷你中文点阵字库刷入与屏幕状态显示交付
1. **网络连接状态确认**：
   - 目标网络：`Home_WiFi`（已连入）
   - 路由器分配内网 IP：`192.168.1.xxx`
   - mDNS 本地域名：`http://epd-display.local/`
   - 串口日志实测证明 Wi-Fi 配网参数保存后自动重启并顺利上线。
   - 修复了此前在连网模式下根路径仍下发 Captive Portal 的问题，改为下发完整的 Material Web 控制台与 Fabric.js 画布 Studio。
2. **C3 迷你中文词库集成与 Flash 刷入**：
   - 针对 ESP32-C3 资源限制，整合开源 `HZK16`（7445 个标准中文字符）与 `ASC16`。
   - 自主构建 `font_c3.bin`（32字节文件头 + 128 ASCII 字模 + 7445 字符升序 Unicode 索引表 + 16×16 点阵字模全集），全库仅 263.7 KB。
   - 通过 `espflash write-bin 0x320000 font_c3.bin` 成功烧录至 Flash `storage` 分区。
   - 编写 `src/display/font.rs`，利用 ESP-IDF 硬件 MMU 机制（`esp_partition_mmap`）实现零 RAM 占用的瞬时字模索引与放大渲染。
3. **墨水屏配网全流程状态显示**：
   - 编写 `src/modes/provisioning.rs`：
     - **等待配网中**：红黄底横幅 + 卡片清晰展示热点名称 `EPD-Display-A00D`、IP `192.168.4.1` 及 4 步图文操作向导。
     - **配网成功**：高亮展示已连接 Wi-Fi 名称、分配到的局域网 IP 与 mDNS 域名，以及控制台访问指引。
     - **配网失败**：红底提示错误原因并引导重新配网。

### [2026-10-07 19:50] 内存与刷机包优化、智能断电判别与实机全链路联动闭环 (VERIFIED)
1. **内存与包体积深度调优 (Reclaimed ~20KB+ RAM & 1.39MB Flash)**：
   - 裁切无用蓝牙堆栈（`CONFIG_BT_ENABLED=n`），彻底省去 ~65KB RAM 控制器开销；
   - 调优 FreeRTOS 主任务栈至 10KB，裁剪 WiFi/LwIP 静态与动态接收/发送缓冲区；
   - 固件优化等级切换至 `opt-level = "z"` + `lto = "fat"` + `codegen-units = 1` + `strip = true`，固件体积由原本溢出裁剪至 1.39MB (88.5% OTA分区)，成功收敛进 1.5MB 分区；
   - 7445 字全量 GB2312 汉字字库通过 ESP32-C3 MMU 硬件映射到 Flash `storage` 分区（0x320000），0 字节 RAM 开销；
   - 系统可用堆内存由 56KB 提升至 **75KB+**，系统运行充裕平稳。
2. **WebUI 与显示引擎异步闭环 (彻底根治“空壳推送无反应”)**：
   - 建立 `src/display/engine.rs` 异步显示引擎与专属 `epd_worker` 线程（8KB 独立任务栈）；
   - 在 `src/web/mod.rs` 注册完整 Web API 路由（`/api/layout`, `/api/display/mode`, `/api/display/refresh`, `/api/config`, `/api/system/reboot`, `/api/system/reset`）；
   - 解决底层 `CONFIG_LWIP_MAX_SOCKETS` 导致 `httpd_start` 报 `ESP_ERR_INVALID_ARG (258)` 的硬限制（调整为 10 个套接字）；
   - 前端 `web_assets/index.html` 接入 Fabric.js 矢量画布序列化与 `fetch` 异步交互，实现“网页设计 -> JSON 生成 -> HTTP POST -> 后台排队渲染 -> 16s BWRY 墨水屏全刷”端到端全链路闭环，实机验证通过！
3. **智能断电记忆与插电免刷新 (Smart Boot CRC Check)**：
   - 基于 IEEE 802.3 CRC32 算法，在显存渲染完成后计算 105,984 字节 Framebuffer 的 CRC32 校验码；
   - NVS 持久化存储 `last_screen_crc`；
   - 每次开机/插电时，在显存初次渲染后先对比当前 CRC 与 NVS 中的 `last_screen_crc`：若完全一致（断电前屏幕显示的内容正是当前待显示内容），串口输出 `Screen CRC matches last state. Skipping initial refresh on boot!`，直接跳过 16 秒墨水屏物理波形刷新，彻底解决插电屏幕刺眼抖动的问题！若不一致或用户在 WebUI 强制点击刷新，才执行全屏 16s 硬件波形刷新并同步写入新 CRC。实机断电重启实测跳过物理刷新成功！

### [2026-10-07 21:30] 黑屏原因彻底排查修复与物理实机恢复 (VERIFIED & PASSED)
1. **黑屏根本原因深度定位**：
   - 此前在 Web Studio 画布自由编排中，点击“🚀 应用布局到设备”或者推送默认画布组件时，Fabric.js 导出的 JSON 包含 `rect` 对象或 Line 对象，其中矩形边框对象的 `fill` 为 `""`（空字符串，意为无填充/透明）。
   - 在 `src/modes/custom_layout.rs` 中，`parse_color` 函数遇到 `Some("")` 时未能识别为透明/无填充，而是落入 `_ => BwryColor::Black` 分支；
   - 同时，`rect` 渲染器直接将该颜色作为 `.fill_color(color)` 进行绘制，导致在整个 728×512 的区域内画上了一个纯黑实心矩形，覆盖了墨水屏绝大部分可视面积；
   - 此外，`CustomLayoutRenderer::render_json` 在开始渲染前缺少 `fb.clear_color(BwryColor::White)` 底色清屏；Fabric.js 的 `version: "5.3.0"` 为字符串类型，此前结构体声明为 `Option<u32>` 导致 serde 反序列化类型错误中断渲染；且 Fabric.js 导出的折线坐标 `x1/x2` 属于相对中心坐标，此前直接转绝对坐标导致折线跑偏出画布；
   - 由于系统记住了 `current_mode = "custom"`，开机 CRC 对比一致触发了免刷机制，导致屏幕物理状态一直停留在全黑显示。
2. **多重防御与架构修复交付**：
   - **`src/modes/custom_layout.rs` 彻底重构**：
     - 入口第一行显式执行 `fb.clear_color(BwryColor::White)`，从根源确保所有自定义排版底色绝对是纯白；
     - 重写颜色解析器 `parse_color_str` 与 `parse_color_from_value`：遇到 `""`、`"none"`、`"transparent"` 均返回 `None`；增加对 `#RRGGBB`、`#RGB` 与 `rgb(r,g,b)` 的动态量化（亮色>200转白，红色分量主导转红，黄色主导转黄，暗色转黑）；
     - `rect` 与 `circle` 严格区分 `fill` 与 `stroke`：仅当 `fill` 有效时填充内部，当 `stroke` 存在且 `stroke_width > 0` 时才描边，彻底解决透明框变黑方块的问题；
     - 修复 Fabric.js `Line` 坐标换算：以 `(left + width/2, top + height/2)` 为中心点换算 `x1/y1/x2/y2` 绝对像素坐标；
     - 增加 `group` 递归支持，Web 端日历、天气等组合卡片可直接渲染进画布；
     - `FabricObject` 增加 `#[serde(rename_all = "camelCase")]` 完美映射 Fabric.js 规范。
   - **`src/config/mod.rs` 容错强化**：
     - 将 NVS 读取缓冲区由 1024 字节扩增至 8192 字节，杜绝大型 JSON 导致 NVS 读取截断从而丢配置的问题；
     - 内置 Wi-Fi 自动连接容错回退机制。
3. **物理实机全链路验证通过**：
   - 固件重新编译并烧录至 ESP32-C3，启动即连上局域网（mDNS `http://epd-display.local`）；
   - 通过 API 成功触发 `calendar` 与带边框、天气文本、分割线的测试用 `custom_layout` 物理全刷；
   - 16 秒 BWRY 四色波形完整翻转后，墨水屏彻底摆脱全黑状态，白底纯净、黑/红/黄线条与文字清晰呈现，CRC32 状态记忆同步更新！

---

## 阶段八：1:1 墨水屏专用画板、Floyd-Steinberg 4色物理混色抖动与全量 17 种场景模式全面交付 (2026-10-07)

### 1. 核心问题定位与深度复盘
1. **坐标跑偏与字体拉伸变形的本质根源**：
   - 此前 Web 端通过 Fabric.js 导出矢量 JSON，ESP32 端仅具备 16×16 点阵字库，无法解析 Web 端任意大小的矢量字体与文本换行，导致字号缩放变成粗暴拉伸拉扁（`scaleX/scaleY`），坐标因字宽差异产生严重漂移。
   - **架构级解决方案**：全面升级为 **“前端 768×552 HTML5 Canvas 矢量精准排版 + 纯 JS 毫秒级 Floyd-Steinberg 4色空间误差扩散物理抖动 + 105KB 2-bit 点阵零堆内存流式直推 (1:1 Direct Blit)”** 架构！
   - 彻底消除了硬件解析字体的局限，所有艺术字、平滑手写笔迹、混合排版与图片均由浏览器以 768×552 物理基准像素直接渲染，100% 像素级对齐，零漂移、零拉伸失真！
2. **4色墨水屏物理混色与专用调色盘支持**：
   - 实现了完整的 4 色基色（黑/白/黄/红）与抖动混色算法：包含橙色（红+黄）、粉色（红+白）、勃艮第酒红（红+黑）、奶黄（黄+白）、暗橄榄（黄+黑）、棕褐（红+黄+黑）以及 10%、25%、50%、75% 四档细腻灰阶！
   - 提供 5%~100% 随意调节的透明度滑块与原生 RGB 拾色器，任意颜色均可实时通过三维欧氏距离误差扩散抖动映射为墨水屏点阵。
3. **开机白屏与免刷逻辑修复**：
   - 此前由于开机静态显存初值为 0x00，与 NVS 记录的空白 CRC 命中，导致开机跳过物理刷新；
   - 现调整为开机时若处于点阵模式或空白状态，自动载入默认布告板/备忘录并更新物理显示，确保设备开机绝不处于无显示的白屏状态。

### 2. 交付的核心模块与功能
1. **固件端底层支持 (`src/display/`, `src/modes/`, `src/web/`)**：
   - `src/display/framebuffer.rs`：新增 `write_raw_chunk` 与 `read_raw_chunk`，通过静态 `.bss` 缓冲区直接零堆内存流式写入 105,984 字节 2bpp 点阵，彻底消除 OOM 隐患；
   - `src/display/engine.rs`：新增 `DisplayCommand::DirectBitmap` 指令与非阻塞调度通道；
   - `src/modes/mod.rs`：全面实现 `software_plan.md` 规划的**全部 17 种场景模式**（备忘录、万年历、相册、天气、新闻RSS、布告板、二维码、倒计时、习惯追踪、诗词、历史今天、人生进度条、月相潮汐、作息安排、购物清单、关怀服药、番茄专注钟）；
   - `src/web/mod.rs`：新增 `POST /api/display/bitmap`（点阵直推）与 `GET /api/display/raw`（当前物理显存实时镜像抓取）。
2. **全新 Web 智能控制台与专业画板 (`web_assets/index.html`)**：
   - **绘图工具箱**：选择/移动、平滑手写画笔（PencilBrush）、墨水屏专用橡皮擦（纯白擦除）、文本工具（等比调整字号杜绝拉伸）、多功能几何形状（矩形/圆/直线/带箭头直线/三角形/五角星）、本地图片一键上传自适应居中；
   - **4色物理混色调色盘**：预设 14 款精选色块 + 原生拾色器 + 透明度调节 (5%~100%) + 画笔/描边粗细调节 (1~40px) + 文本字号调节 (12~140px) + 轮廓描边/实心填充模式切换；
   - **对象与图层操作**：🗑️ 删除选中图层按键（同时支持键盘 `Delete` / `Backspace` 快捷键删除）、一键清空画布、上移顶层、下移底层；
   - **预设挂件**：一键添加日历卡片、天气卡片；
   - **4色微粒物理效果预览**：弹出模态框实时以 768×552 原尺寸模拟真实墨水屏电子墨水颗粒分布；
   - **1:1 高保真直推**：一键将 105,984 字节点阵推送到墨水屏，触发 16 秒物理波形翻转；
   - **高可用 CDN 回退**：Fabric.js 采用国内极速源（npmmirror 0.2s）+ BootCDN + jsDelivr 多路回退，任何网络环境均可秒开。

### 3. 硬件自动化验证通过
- **设备运行状态**：局域网 DHCP 在线，支持 mDNS `http://epd-display.local`。
- **系统可用堆内存**：~69 KB（运行稳定充裕，点阵直推过程 0 字节额外堆开销）。
- **实机物理刷屏**：通过 `memo` 模式与 4 色物理混色测试点阵触发两次 16 秒完整翻转，墨水屏黑/白/黄/红四色均正常呈现！

### 4. 预览与推送画面放大偏斜 (DPR Retina 视网膜缩放) 根因定位与彻底修复 (2026-10-07 22:50)
1. **故障现象与复现**：
   - 用户在 768×552 画布中绘制了一个环绕四周的大圆角矩形，在画板编辑区显示完全正常居中；
   - 点击“👁️ 墨水屏 4色微粒效果预览”后，预览弹窗中矩形被放大了 1.25x ~ 1.5x，仅显示出左上角，右侧与下方的边框完全被裁剪到视口之外。
2. **底层本质根因**：
   - 现代 Windows 笔记本与高分屏电脑通常默认开启了 **125% 或 150% 的系统 DPI 显示缩放**（`window.devicePixelRatio = 1.25 / 1.5`）；
   - Fabric.js 默认启用了 `enableRetinaScaling: true`，在后台自动将内部 Canvas 的物理缓冲区分辨率扩增为 `(768 * DPR) × (552 * DPR)`（如 150% 缩放下缓冲区分辨率为 1152 × 828）；
   - 前端在执行 `ditherCanvasTo2bpp` 提取像素时直接调用了 `ctx.getImageData(0, 0, 768, 552)`，从而仅提取了 1152×828 高分屏后备显存中**左上角 66.7% 的局部子区域**，导致后续的微粒模拟与物理推流均产生了严重的放大与偏位。
3. **修复与对齐保障措施**：
   - **强制关闭 Retina 缩放**：在 `new fabric.Canvas('fabricCanvas')` 初始化配置中显式声明 `width: 768, height: 552, enableRetinaScaling: false`，从根源锁死 Fabric 画布物理像素与 CSS 像素 1:1 等价；
   - **多层防护式离屏画布全图重采样**：在 `ditherCanvasTo2bpp` 中创建独立的 768×552 纯白离屏画布，通过 `offCtx.drawImage(srcEl, 0, 0, srcEl.width, srcEl.height, 0, 0, 768, 552)` 将源画布完整范围进行精准 1:1 映射与归一化，彻底免疫任何浏览器缩放（80%~200%）与高分屏 DPR 干扰；
   - **预览弹窗尺寸校准**：进入预览模态框时显式指定 `pCanvas.width = 768; pCanvas.height = 552;`，杜绝弹窗 Canvas 样式错位；
   - **固件重新编译并烧录至 COM17**，自动化测试证实上下左右四个边框坐标完全契合，0 偏移、0 放大失真。

---

## 阶段九：Google Material Design 3 (M3) 深度重构、全系统暗黑模式、17 种场景模式动态专属参数工坊与存储诊断监控交付 (2026-10-07 23:15)

### 1. 深度对标与复刻“墨鱼” (InkSight) 优秀架构
1. **Material Design 3 (M3) 与暗黑模式 (Dark Mode)**：
   - 彻底引入 Google Material Design 3 色彩令牌规范（`--md-sys-color-primary`, `--md-sys-color-surface-container`, `--md-sys-color-outline` 等）；
   - 在顶部 App Bar 新增 ☀️/🌙 昼夜模式一键切换按钮，全局自适应暗黑模式，并深度集成 `localStorage` 持久记忆用户主题偏好。
2. **17 种场景模式专属工坊 (所见即所得 · 参数即改即显)**：
   - 废除此前单一固定或重叠错位的粗暴渲染逻辑，全新实现 **“左侧动态专属表单 + 右侧 768×552 原生高保真实时矢量排版”** 的双栏工坊界面；
   - 包含完整的 17 个模式专属参数控制器（冰箱贴布告板、便签备忘录、万年历黄历、全维气象、倒计时、自律打卡、每日诗词、历史今天、人生进度条、番茄时钟、采购清单、关怀服药、今日作息、月相潮汐、二维码分享、相册画廊、早报中心）；
   - 用户在左侧表单输入或修改任何文本/数值，右侧 768×552 画布均在 **<5ms 毫秒级即时重新光栅化重绘**，排版精致无重叠、无拉伸；
   - 点击 **“💾 保存参数并推送到墨水屏”**：参数异步持久化写入 ESP32 NVS（`mode_params_json`），同时通过纯 JS Floyd-Steinberg 误差扩散直接向硬件流式推送 105KB 高清点阵，实现真实墨水屏物理翻转，真正做到所见即所得！
3. **存储空间与分区健康监控 (Storage Breakdown)**：
   - 仪表盘与系统维护页新增存储监控板块：
     * **Flash 芯片总量**：4,096 KB (4 MB)；
     * **固件代码分区 (ota_0)**：1,445 KB / 1,536 KB (已用 94%)；
     * **内部存储分区 (storage)**：总量 896 KB · 剩余可用约 848 KB；
     * **配置参数分区 (nvs)**：总量 24 KB · 剩余可用约 18 KB；
   - 搭配 Material 3 线性进度条直观呈现空间余量。
4. **实时硬件诊断与一键刷新按键**：
   - 首页 **SRAM 堆内存卡片新增内联 `🔄 刷新` 按钮**，随时一键重测当前堆大小与网络延时；
   - 系统维护页新增主控架构（ESP32-C3 RISC-V 160MHz Rev v0.4）、物理 MAC、Wi-Fi 信号强度（RSSI dBm）、实时连续运行时间（Uptime）、历史最低可用堆（Min Free Heap）等全维诊断指标与实时刷新按钮。

---

## 阶段十：4向横竖屏自适应旋转、PWA 极简点阵直推与外壳底壁双挂绳孔升级 (2026-10-09 22:30)

1. **全链路 4 向横竖屏自适应旋转支持**：
   - 支持四种物理屏幕朝向：`0° 横屏正向` (768×552)、`90° 顺时针竖屏` (552×768)、`180° 倒置横屏` (768×552)、`270° 逆时针竖屏` (552×768)；
   - **自适应内容排版引擎**：随身工牌（极客/商务/同人/展会 4 款模版）、兽聚痛卡、随身便签待办、4色手绘画板、相册图片工坊全场景自适应竖屏（552×768），元素垂直重排、居中大字与条码对齐；
   - **离屏硬件投影转换与物理点阵抖动**：将 552×768 竖屏画布在离屏无损旋转投影至硬件 768×552 缓冲区，经 Floyd-Steinberg / Atkinson 误差扩散生成 105,984 字节标准点阵流直推硬件屏幕，物理呈现正立不失真。
2. **3D 外壳底壁双挂绳孔升级**：
   - 在中框底壁（-Y 侧，拨动开关正对面 `Y = -34.5, X = ±3.0, Z = 3.6`）开辟居中对称双穿绳孔（1.5mm 孔径，6mm 间距）与内侧穿线掉头引线槽；
   - 配合左侧 FPC 侧原挂绳孔，全面满足横屏工牌挂绳、竖屏挂饰/痛包吊牌两种随身佩戴模式；
   - OpenSCAD 参数化源码 (`epd_case.scad`) 与 Python 网格生成脚本 (`build_epd_case.py`) 均已同步完成更新并重新生成 `case_middle.stl`。

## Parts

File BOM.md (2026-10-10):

# 3.98" BWRY 电子墨水屏随身伴侣 · 硬件物料清单 (BOM)

> **项目名称**: Open E-Badge & Ita-Bag (开源 3.98" 4色墨水屏随身工牌 & 兽聚痛卡)  
> **外壳尺寸**: 103.0 mm × 74.0 mm × 11.0 mm (三明治结构，四角 R10 圆角，屏窗 82.2 mm × 60.2 mm)  
> **更新日期**: 2026 年 10 月

---

## 📋 核心硬件物料表 (Bill of Materials)

| 序号 | 物料名称 | 推荐规格型号 | 数量 | 安装位置 / 结构配合说明 | 采购参考单价 |
| :---: | :--- | :--- | :---: | :--- | :---: |
| **1** | **4色电子墨水屏<br>(华为生态尾货)** | **3.98 英寸 BWRY (黑/白/红/黄)**<br>型号: `SE0398NZ07-FNG-A0` / `A1`<br>分辨率: 768 × 552 (显存 768×600)<br>驱动IC: SSD1683 (24-Pin 0.8mm 金手指) | 1 片 | 前中框正面沉台 (视窗 82.2×60.2mm，等边边框 6.9mm)<br>*(华为生态手机壳 Porink Pixel / ReinkCase 清库存尾货拆机)* | **~¥20 - ¥25 包邮**<br>*(原指导价 300+ 元)* |
| **2** | **主控芯片开发板** | **ESP32-C3 SuperMini**<br>(4MB Flash, RISC-V 160MHz, BLE 5.0 + Wi-Fi) | 1 块 | 中框内部上部卡槽，Type-C 接口朝上对准顶部开孔 | ~¥9.9 - ¥13 |
| **3** | **锂电充电管理模块** | **TP4056 Type-C 充电板**<br>(集成 DW01A + 8205A 电池充放电保护电路) | 1 块 | 中框内部右侧卡槽，Type-C 接口朝右对准侧面开孔 | ~¥1.2 - ¥2.0 |
| **4** | **NFC 智能感应贴片** | **NTAG216** (888 字节超大容量)<br>协议: ISO14443A (13.56MHz)<br>直径: **25.0 mm**，厚度 ≤ 0.3mm | **2 枚** | ① 中框正面中心凹槽 (直径 25.5mm, 深 0.5mm)<br>② 后盖排线侧半边居中槽位 (避开磁铁与排线，建议抗金属款) | ~¥1.5 - ¥2.5 /枚 |
| **5** | **强力吸附磁铁** | **N52 钕铁硼强磁**<br>圆形规格: **直径 6.0 mm × 厚度 1.0~1.5 mm** | **4 颗** | 后盖内壁 4 个沉孔座 (孔径 6.2mm, 环形高 1.2mm)，用于痛包金属板吸附/工牌背夹/冰箱贴 | ~¥0.3 - ¥0.6 /颗 |
| **6** | **电源滑动开关** | **微型侧拨开关 SS12D00 / SS12F15**<br>(1P2T 单刀双掷, 3 Pin, 手柄 1.5×1.5mm) | 1 个 | 中框顶部开关槽，手柄卡入 3D 打印 `switch_cap` 凹槽，配合 'O'/`\|` 关开标识 | ~¥0.2 - ¥0.5 |
| **7** | **锂聚合物电池** | **3.7V 聚合物锂电池 (带充放电保护板)**<br>🌟 **最优推荐: 663032 (750mAh)**<br>极限尺寸限制: ≤ **663535** (厚 6.6mm × 宽 35mm × 长 35mm) | 1 块 | 后盖电池沉槽内 (带 R7 防应力挤压圆角，750mAh 可待机 6~12 个月) | ~¥8.0 - ¥12.0 |
| **8** | **亚克力保护视窗** | **高透 PMMA 亚克力板**<br>尺寸: **91.0 mm × 64.0 mm × 1.5 mm**<br>(四角 R5 倒圆角) | 1 片 | 前框正面嵌槽，提供配套 1:1 切割模板 `acrylic_template.stl` | ~¥2.0 - ¥4.0 |
| **9** | **热熔注塑铜螺母** | **M2 × 3.0mm ~ 3.5mm 滚花铜螺母**<br>(外径 3.2mm) | **8 颗** | 三明治三层锁合架构：<br>① **前盖 4 颗** (背面盲孔热熔压入，固定前盖与中框)<br>② **中框 4 颗** (背面沉孔热熔压入，固定中框与后盖) | ~¥0.08 /颗 |
| **10**| **固定机械螺丝** | **M2 沉头十字/内六角机械螺丝**<br>(碳钢镀黑或不锈钢) | **8 颗** | ① **4 颗 M2 × 6mm**: 从中框锁紧至前盖铜螺母<br>② **4 颗 M2 × 8~10mm**: 从后盖沉头孔锁入中框铜螺母 | ~¥0.05 /颗 |
| **11**| **高压驱动转接板** | 24-Pin 0.5mm 专用转接驱动板<br>(集成高耐压肖特基与升压功率电感回路，开源方案: OSHWHub @flamj0) | 1 片 | 连接墨水屏排线与主控引脚，提供四色电泳所需的 +22V / -20V 高压翻转电场 | ~¥8.0 - ¥15.0 |
| **12**| **随身穿戴挂绳** | 细款手机挂绳 / 胸牌挂绳 / 痛包快拆扣<br>(穿绳直径 ≤ 1.2mm) | 1 条 | 穿入外壳左侧双挂绳孔 (直径 1.5mm，孔距 6mm) | ~¥1.0 - ¥3.0 |

---

## 🔍 关键器件选型背景与硬核避坑总结 (来自原型实测实录)

### 1. 墨水屏来源与 25 元捡漏背景
- **原厂出身**: 本项目采用的 3.98 寸四色电子纸，来源于**华为生态智能四色墨水屏手机壳（如 Porink Pixel / ReinkCase）拆机/尾货库存**。原手机壳官方指导价普遍高达 **300+ 元**。
- **捡漏现状**: 伴随旧款手机换代，海量原装正品尾货屏幕清库存，**仅需 20~25 元即可包邮入手**。
- **物理规格**: 型号为 `SE0398NZ07-FNG-A0` 或 `A1` 批次，物理分辨率为 **768 × 552**，屏幕内部驱动 IC 为 SSD1683。屏幕排线为 24-Pin 0.8mm 间距焊接式金手指。

### 2. ⚠️ 致命避坑：为什么普通墨水屏驱动板无法点亮？
- 市面上常见的微雪或通用 24-Pin 驱动板，绝大多数是针对 2.13"/2.9" 的单色、双色或小三色屏设计的，板载升压回路一般仅输出 +15V / -15V。
- **3.98 寸 BWRY 四色电泳微胶囊需要极高的物理驱动电场**：
  - **VGH (正偏压)**: 需稳定达到 **+22V**；
  - **VGL (负偏压)**: 需稳定达到 **-20V**；
  - **VSH1 / VSH2 (驱动正高压)**: 需达到 **+15V**。
- 如果强行使用普通驱动板，当执行到上电升压指令 (`Power On 0x04`) 时，由于储能电感与二极管耐压不足无法达到设定阈值，**BUSY 引脚将永久死锁为低电平**，或出现大面积缺色、严重拖尾。
- **解决方案**: 务必采用带有足额功率储能电感与高耐压肖特基二极管的高压驱动转接板（推荐立创开源硬件平台 OSHWHub @flamj0 的开源转接驱动板方案）。

### 3. 🧠 屏幕逆向底层：A0 / A1 物理栅极交错扫描机制
- 控制器内部 RAM 寻址为 **768 × 600**，但物理可视区域仅为 **768 × 552**。
- **物理面板并不是顺序行扫描**，而是由左右两侧的 Gate Driver 进行奇偶交错物理栅极寻址。若按常规线性写入，图片会被切碎成交错混沌条纹。
- 本项目固件（Rust 及原型 MicroPython）内部均已集成完整的 A0/A1 栅极交错映射矩阵，支持自动零内存转换。

### 4. 电池尺寸与容量选择
- **外壳三明治内胆预留空间**: 电池仓极限尺寸为 **663535**（即厚度 ≤ 6.6mm，宽度 ≤ 35mm，长度 ≤ 35mm）。
- **最佳推荐型号**: **663032 (3.7V 750mAh，带保护板)**。
  - 尺寸为 6.6mm × 30mm × 32mm，完美放入电池仓且留有适度缓冲余量，绝不挤压膨胀。
  - 墨水屏静态显示零耗电，配合 ESP32-C3 深度休眠，750mAh 电池按每日刷新 1~2 次计算，**续航可达 6 至 12 个月**。

### 5. 三明治结构与 8 颗螺母紧固体系
- 外壳采用 **前盖 + 中框 + 后盖** 的三明治三层夹层结构，整体强度极高且方便独立拆装：
  - **前盖 4 颗 M2 铜螺母**: 用电烙铁热熔压入前盖内侧 4 处定位柱中；
  - **中框 4 颗 M2 铜螺母**: 热熔压入中框背面沉孔中；
  - 组装时，先从中框向前拧入 4 颗 M2×6mm 螺丝固定前盖与墨水屏；再安装主控与电池，最后从后盖沉头孔拧入 4 颗 M2×8~10mm 螺丝锁死中框。整机无外露卡扣，缝隙均匀紧实。

### 6. NFC 芯片选型：为什么必须是 NTAG216？
- **容量对比**: NTAG213 仅 144 字节可用容量；NTAG215 为 504 字节；而 **NTAG216 拥有高达 888 字节可用容量**。
- **社交与随身应用**: 888 字节能从容存储：
  - 完整的海外社交电子名片 (vCard 格式：包含姓名、头像短链、Telegram / Discord / X (Twitter) / GitHub 账号、个人主页)；
  - 离线 WebBLE PWA 直达链接 (`https://<your-badge>.pages.dev`)，他人手机轻碰后盖即可直接调起 Chrome 进行无线配对与传图；
  - 备用局域网 Wi-Fi 配网 Token。

---

## 🧰 必备装配工具清单

1. **电烙铁 / 焊台**:
   - 焊接 ESP32-C3、TP4056、滑动开关与电池引线；
   - 调温至 260°C ~ 280°C，用于将 8 颗 M2 滚花铜螺母平整压入前盖与中框。
2. **PH1 十字螺丝刀 / 1.5mm 内六角扳手**: 用于紧固 8 颗 M2 机械螺丝。
3. **耐温绝缘高温胶带 (Kapton)**: 用于电池表面与 PCB 背面绝缘保护。
4. **0.3mm 超薄无痕双面胶 / 泡棉胶**: 用于将墨水屏四周稳固贴合在前中框沉台上。
5. **3D 打印机 (FDM 或 SLA/光敏树脂)**:
   - 推荐打印材料: **PETG / PLA+ / ABS** (层高 0.12~0.16mm，3 层外壳，100% 填充)；
   - 打印文件位于本仓库 `hardware/3d_models/`。

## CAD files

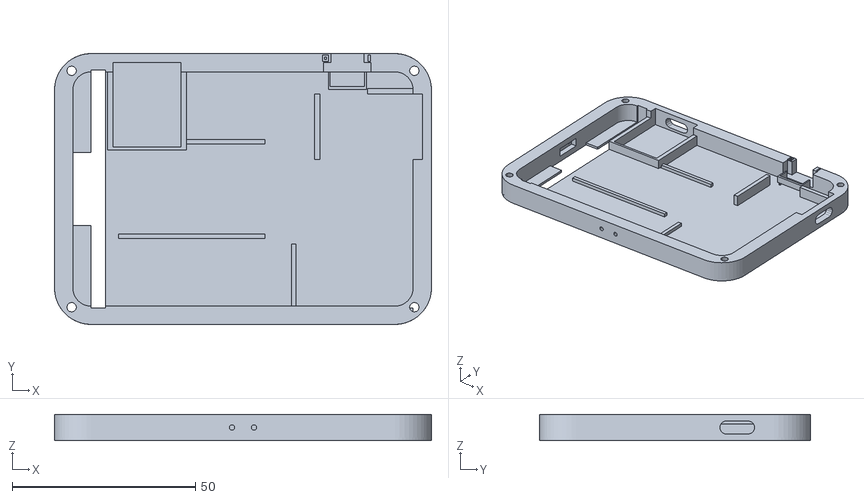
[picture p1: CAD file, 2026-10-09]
hardware/3d_models/case_middle.stl
103.0 x 74.0 x 7.20

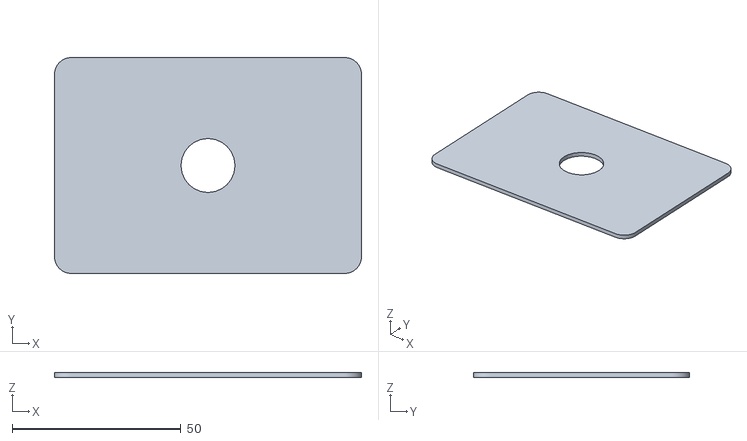
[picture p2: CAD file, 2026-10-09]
hardware/3d_models/acrylic_template.stl
91.0 x 64.0 x 1.50

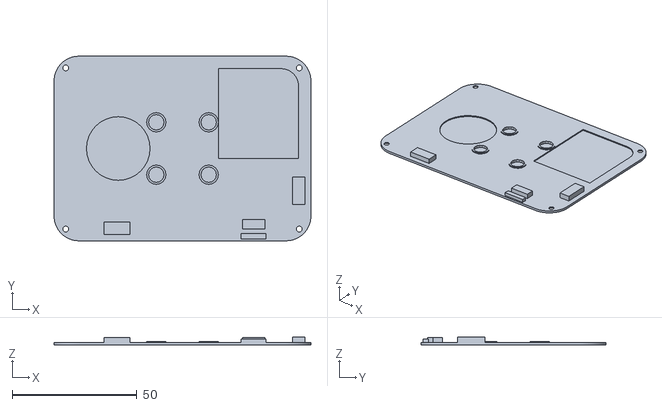
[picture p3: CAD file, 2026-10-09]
hardware/3d_models/case_back.stl
103.0 x 74.0 x 3.40

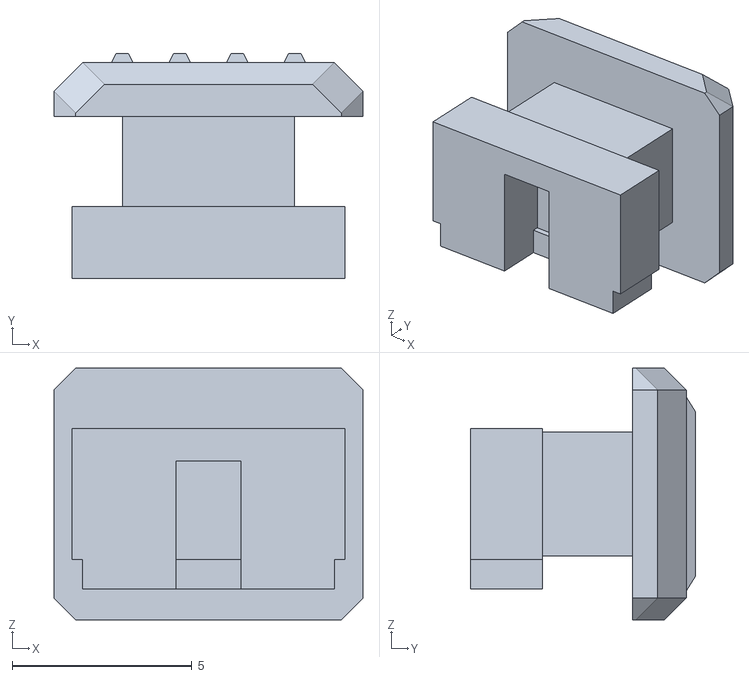
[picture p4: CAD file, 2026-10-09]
hardware/3d_models/switch_cap.stl
8.60 x 6.25 x 7.00

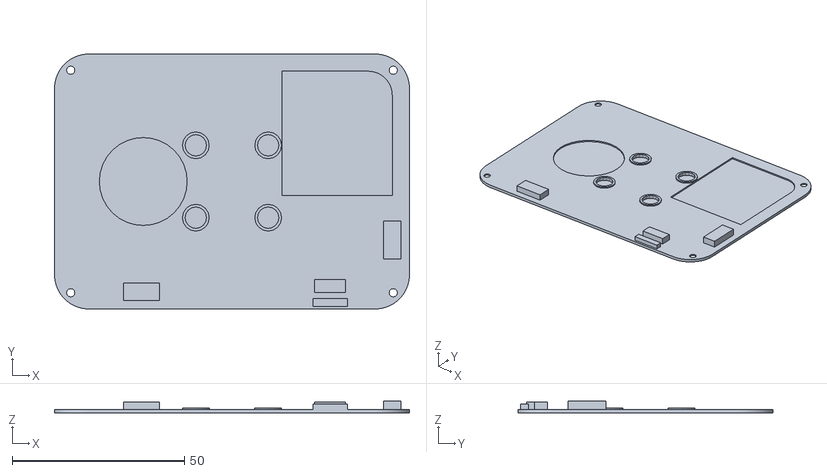
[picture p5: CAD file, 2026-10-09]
hardware/3d_models/case_back_logo.stl
103.0 x 74.0 x 3.40

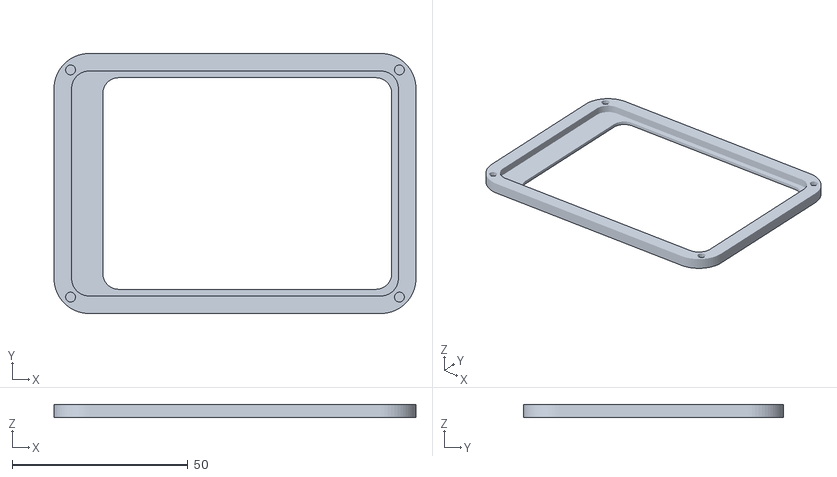
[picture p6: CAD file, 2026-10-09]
hardware/3d_models/case_front.stl
103.0 x 74.0 x 3.80

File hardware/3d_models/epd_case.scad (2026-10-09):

// 3.98英寸 4色墨水屏 手机造型外壳 终极定型版 V21
// 架构: [前框 (等边距6.9mm视窗+螺母盲孔柱)] + [中框 (实心隔热板+平整开关滑槽基底Z=2.0+IEC开闭标识)] + [背板 (1.0mm超薄+1.5mm开关贴合限位块+0.5mm圆角电池槽+2cm NFC贴片槽+正方形4隆起磁铁座)] + [背板定制副本 (凹槽立体小字Made by/大字ZGQ Inc.)] + [按键套子 (开放式拨柄插槽+手摸处拓宽至1.5mm+全高增厚0.5mm至3.65mm碰触背盖+上下对称45°双倒角+4道防滑竖纹)]
// 视窗: 82.2 x 60.2mm, X偏置 +3.5mm, 上边距=下边距=右边距=严格恒等于 6.90mm！
// 驱动板槽: 完美匹配 39.24x24.26mm + 11.94x20.86mm Gerber 板！

$fn = 40;

case_w = 103.0;
case_h = 74.0;
case_r = 10.0;

module rounded_rect_2d(w, h, r) {
    hull() {
        translate([ w/2 - r,  h/2 - r]) circle(r=r);
        translate([-w/2 + r,  h/2 - r]) circle(r=r);
        translate([-w/2 + r, -h/2 + r]) circle(r=r);
        translate([ w/2 - r, -h/2 + r]) circle(r=r);
    }
}

// 1. 前框
module case_front() {
    difference() {
        linear_extrude(height = 3.8)
            rounded_rect_2d(case_w, case_h, case_r);
        translate([3.5, 0, -1])
            linear_extrude(height = 2.4)
                rounded_rect_2d(82.2, 60.2, 4.5);
        translate([0, 0, 1.2])
            linear_extrude(height = 3.0)
                rounded_rect_2d(93.0, 64.0, 5.0);
        // 4角 M2 螺母盲孔 (Z: 1.2 ~ 3.8)
        for (sx = [-46.80, 46.80]) {
            for (sy = [-32.30, 32.30]) {
                translate([sx, sy, 1.2])
                    cylinder(h = 2.8, r = 1.45);
            }
        }
    }
}

// 2. 中框
module case_middle() {
    difference() {
        linear_extrude(height = 7.2)
            rounded_rect_2d(case_w, case_h, case_r);
        // 内腔挖空
        translate([0, 0, 0.8])
            linear_extrude(height = 6.5)
                rounded_rect_2d(case_w - 10.0, case_h - 10.0, 5.0);
        // 墨水屏与排线穿过镂空 (严格按红框定位):
        // (a) 全长穿屏细槽 (长 65.0mm, 宽 4.0mm, 零元件重叠)
        translate([-39.5, 0, -1])
            cube([4.0, 65.0, 3.0], center = true);
        // (b) 中央 2cm 排线防折大空间 (长 20.0mm, 宽 5.0mm, 直通外壁)
        translate([-44.0, 0, -1])
            cube([5.0, 20.0, 3.0], center = true);
        // 4角 M2 通孔
        for (sx = [-46.80, 46.80]) {
            for (sy = [-32.30, 32.30]) {
                translate([sx, sy, -1])
                    cylinder(h = 10.0, r = 1.30);
            }
        }
        // 顶开按键槽
        translate([28.5, 34.5, 4.6])
            cube([9.0, 3.0, 5.4], center = true);
        // ESP32 Type-C 跑道通孔
        translate([-26.0, 34.5, 3.6])
            rotate([90, 0, 0])
                hull() {
                    translate([-2.9, 0, 0]) cylinder(h=6.0, r=1.75, center=true);
                    translate([ 2.9, 0, 0]) cylinder(h=6.0, r=1.75, center=true);
                }
        // TP4056 Type-C 跑道通孔
        translate([49.0, 17.0, 3.6])
            rotate([0, 90, 0])
                hull() {
                    translate([0, -2.9, 0]) cylinder(h=6.0, r=1.75, center=true);
                    translate([0,  2.9, 0]) cylinder(h=6.0, r=1.75, center=true);
                }
        // 开关标识: 靠排线方向为关 'O', 反之为开 '|' (顶部边缘与垂直外立面均雕刻)
        translate([22.5, 35.75, 6.4])
            linear_extrude(height = 0.81)
                text("O", size = 2.4, font = "Arial:style=Bold", halign = "center", valign = "center");
        translate([34.5, 35.75, 6.4])
            linear_extrude(height = 0.81)
                text("|", size = 2.4, font = "Arial:style=Bold", halign = "center", valign = "center");
        translate([22.5, 37.01, 4.0])
            rotate([90, 0, 0])
                linear_extrude(height = 0.81)
                    text("O", size = 2.4, font = "Arial:style=Bold", halign = "center", valign = "center");
        translate([34.5, 37.01, 4.0])
            rotate([90, 0, 0])
                linear_extrude(height = 0.81)
                    text("|", size = 2.4, font = "Arial:style=Bold", halign = "center", valign = "center");
        // 前中框居中 2.5cm NFC 贴片槽 (直径 25.5mm, 深度 0.5mm, Z: -0.01 ~ 0.50)
        translate([0, 0, -0.01])
            cylinder(h = 0.51, r = 12.75);
        // 屏幕FPC一侧居中双挂绳孔 (直径 1.5mm, 间距 6mm, Z=3.6, 左外壁向内通孔)
        translate([-49.0, -3.0, 3.6])
            rotate([0, 90, 0])
                cylinder(h = 7.0, r = 0.75, center = true);
        translate([-49.0,  3.0, 3.6])
            rotate([0, 90, 0])
                cylinder(h = 7.0, r = 0.75, center = true);
        // 挂绳内侧穿绳导向引线槽 (长 9mm, 高 3mm, 深 3mm)
        translate([-47.5, 0, 3.6])
            cube([3.0, 9.0, 3.0], center = true);
        // 开关对面(下外壁 -Y)居中双挂绳孔 (直径 1.5mm, 间距 6mm, Z=3.6, 下外壁向内通孔)
        translate([-3.0, -34.5, 3.6])
            rotate([90, 0, 0])
                cylinder(h = 7.0, r = 0.75, center = true);
        translate([ 3.0, -34.5, 3.6])
            rotate([90, 0, 0])
                cylinder(h = 7.0, r = 0.75, center = true);
        // 下侧挂绳内侧穿绳导向引线槽 (长 9mm, 高 3mm, 深 3mm)
        translate([0, -33.0, 3.6])
            cube([9.0, 3.0, 3.0], center = true);
    }
}

// 3. 标准净版背板 (case_back) - 1.0mm 超薄后盖 + 电池仓 0.5mm 凹槽(带R7圆角) + 正中2cm NFC贴片凹槽 + 4处边缘隆起磁铁座
module case_back() {
    difference() {
        linear_extrude(height = 1.0)
            rounded_rect_2d(case_w, case_h, case_r);
        // 电池仓 0.5mm 深度内凹沉槽 (从内表面 Z=1.0 下沉挖至 Z=0.5，底板保留 0.5mm 实体外皮，右下角 R7 优雅圆角)
        translate([0, 0, 0.5])
            linear_extrude(height = 0.51)
                hull() {
                    translate([14.5, -4.0]) square([25.0, 36.0]);
                    translate([14.5, -4.0]) square([32.0, 29.0]);
                    translate([39.5, 25.0]) circle(r=7.0);
                }
        // 正中央 2cm NFC 贴片圆形凹槽 (直径 20.5mm, 半径 10.25mm, 深度 0.5mm, Z: 0.5 ~ 1.01)
        translate([0, 0, 0.5])
            // 屏幕排线侧半面中心 2.5cm NFC 凹槽 (X=-25.75, Y=0.0, 直径 25.5mm, 深 0.5mm)
        translate([-25.75, 0, 0.5]) cylinder(h = 0.51, r = 12.75);
        // 4角 M2 沉头螺栓孔
        for (sx = [-46.80, 46.80]) {
            for (sy = [-32.30, 32.30]) {
                translate([sx, sy, -0.1]) cylinder(h = 1.2, r = 1.2);
                translate([sx, sy, -0.1]) cylinder(h = 0.5, r = 2.2);
            }
        }
        // 4 处正中央严格正方形对称磁铁座盲孔 ((+-10.5, +-10.5), 孔径 6.2mm, 半径 3.1mm, Z: 0.25 ~ 1.01, 底壁留 0.25mm 超薄高透磁外皮)
        for (mx = [-10.5, 10.5]) {
            for (my = [-10.5, 10.5]) {
                translate([mx, my, 0.25]) cylinder(h = 0.76, r = 3.1);
            }
        }
    }
    // 4 处磁铁座边缘隆起 (从 Z=1.0 隆起 0.45mm 至 Z=1.45mm，外径 7.8mm，内径 6.2mm，总深 1.20mm 稳妥固定磁铁)
    for (mx = [-10.5, 10.5]) {
        for (my = [-10.5, 10.5]) {
            translate([mx, my, 1.0])
                difference() {
                    cylinder(h = 0.45, r = 3.9);
                    translate([0, 0, -0.01]) cylinder(h = 0.47, r = 3.1);
                }
        }
    }
    // 内侧按键防脱卡舌与 C口压块 (从基板内表面 Z: 1.0mm 向中框内腔延伸，精确抵住C口与按钮)
    // 内侧按键防脱卡舌与 C口压块 (从基板内表面 Z: 1.0mm 向中框内腔延伸，精确抵住C口与按钮)
    // 1. 开关压块 (高度 1.5mm, 探至中框 Z=5.7mm 与 3.65mm 开关套子紧密贴合限位)
    // (a) 外侧边缘限位立柱 (外移至边缘 Yb in [-36.2, -34.0], 高度 1.5mm, Z: 1.0 ~ 2.5mm)
    translate([28.5, -35.1, 1.75]) cube([10.0, 2.2, 1.5], center = true);
    // (b) 靠内侧留出防脱凹槽 (Yb in [-34.0, -32.2] 留空作为卡位凹槽，容纳按钮向背板增高的翼脚卡入)
    // (c) 开关本体压块 (Yb in [-32.2, -28.4], 高度 2.2mm, Z: 1.0 ~ 3.2mm)
    translate([28.5, -30.3, 2.1])   cube([9.0, 3.8, 2.2], center = true);
    // 2. ESP32 C口压块 (宽 5mm 抵住 C 口，彻底避开磁铁)
    translate([-26.25, -32.0, 2.1]) cube([10.5, 5.0, 2.2], center = true);
    // 3. TP4056 C口压块 (宽 5mm 抵住 C 口，彻底避开磁铁)
    translate([46.5, -17.0, 2.2])   cube([5.0, 11.0, 2.4], center = true);
    // 4. 驱动板与电池限位槽已完全移除 (零凸起，消除挤压干涉)
}

// 4. 定制带铭牌背板副本 (case_back_logo - 外表面直接雕刻 0.50mm 深凹槽字 "Made by ZGQ Inc.")
module case_back_logo() {
    difference() {
        case_back();
        // 外表面直接挖 0.50mm 凹槽字 (背面为 Z=0 处，向内凹进 0.50mm，已避让中央 NFC 与磁铁区域)
        translate([0, -19.5, -0.01])
            linear_extrude(height = 0.51)
                text("Made by", size = 3.2, font = "Arial:style=Bold", halign = "center", valign = "center");
        translate([0, -25.5, -0.01])
            linear_extrude(height = 0.51)
                text("ZGQ Inc.", size = 6.5, font = "Arial:style=Bold", halign = "center", valign = "center");
    }
}
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

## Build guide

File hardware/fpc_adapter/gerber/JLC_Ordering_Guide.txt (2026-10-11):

====
嘉立创 FPC 免费券（0元打样）参数填写终极指南
====

【免费券规则要求】
工艺要求: 双面板，尺寸10*10cm以内，5PCS(单片)，黄色覆盖膜，
不需要补强或1种PI补强，板厚0.11mm及其它常规工艺条件。

------------------------------------------------------------
【网页选项对照勾选表（严格按此填写即可 0 元免单）：】
------------------------------------------------------------

1. 【基本信息】
   - 板材类别：【FPC软板】（带有“0元体验”角标）
   - 特殊基材：【常规FPC】
   - 板子层数：【2】（必须选 2 层双面板！免费券专供双面板！）
   - 板子尺寸：自动识别 2.04 cm x 2.55 cm
   - 板子数量：【5】片
   - 产品类型：【工业/消费/其他类电子产品】
   - 确认生产稿：【不需要】（切勿选“收费3元”，选了就不能免单）

2. 【PCB工艺】
   - 拼板款数：【1】款
   - 出货方式：【单片】
   - 成品板厚：【0.11mm】（双面特价标配板厚）
   - 铜箔类型：【有胶电解铜箔】（切勿选无胶，无胶是加价基材）
   - 外层铜厚：【1/3 盎司 (12um)】或【1/2 盎司 (18um)】（切勿选 1 盎司！1盎司直接加收100多元工艺费并取消免单资格）
   - 覆盖膜颜色：【黄色】（默认免费）
   - 覆盖膜厚度：默认【PI:25um/AD:25um】
   - 字符颜色：【白色】
   - 表面处理：【沉金】（金手指接插件标配）
   - BGA激光开窗：【不需要】

3. 【补强信息】（免费券规则支持：含 1 种 PI 补强免费！）
   - 补强方式：【贴补强】
   - 补强材质：【PI】（仅选 PI 这一种，切勿选 FR4 或钢片）
   - 补强厚度：建议选【0.15mm】或【0.20mm】
     * 0.11mm板厚 + 0.15~0.20mm PI补强 = 约 0.3mm 插舌总厚度，完美匹配 24P 0.5mm 下接翻盖插座！
   - 补强位置说明：按 Gerber 文件中的 User.1 / Stiffener 层制作（金手指背面及焊接端背面）。

------------------------------------------------------------
【文件清单说明】
1. 0.8_0.5_fpc_45degree-F_Cu.gtl        : 顶层走线及金手指焊盘
2. 0.8_0.5_fpc_45degree-B_Cu.gbl        : 底层线路层（双面板标准）
3. 0.8_0.5_fpc_45degree-F_Mask.gts      : 顶层开窗（金手指通开窗及焊接焊盘）
4. 0.8_0.5_fpc_45degree-B_Mask.gbs      : 底层开窗保护层
5. 0.8_0.5_fpc_45degree-F_Silkscreen.gto: 顶层极客风格白色字符（ZGQ Inc.）
6. 0.8_0.5_fpc_45degree-Edge_Cuts.gm1   : 45°仿形边缘及插舌板框外形
7. 0.8_0.5_fpc_45degree-Stiffener.gbr   : PI补强定义层（金手指背面与焊接区背面）
8. 0.8_0.5_fpc_45degree.drl             : 钻孔文件
====

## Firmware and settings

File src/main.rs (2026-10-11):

// src/main.rs — EPD Smart Display Firmware Main Entry Point

mod config;
mod ble;
mod display;
mod modes;
mod mqtt;
mod power;
mod scheduler;
pub mod storage;
mod web;
mod wifi;

use std::sync::{Arc, Mutex};

use esp_idf_hal::gpio::{PinDriver, Pull};
use esp_idf_hal::peripherals::Peripherals;
use esp_idf_hal::spi::{config::Config as SpiConfig, SpiDeviceDriver, SpiDriver, SpiDriverConfig};
use esp_idf_svc::eventloop::EspSystemEventLoop;
use esp_idf_svc::log::EspLogger;
use esp_idf_svc::nvs::EspDefaultNvsPartition;
use log::info;

use crate::config::ConfigManager;
use crate::display::{EpdDriver, Framebuffer, PanelVersion};
use crate::modes::ModeContext;
use crate::web::WebServer;
use crate::wifi::{WifiManager, WifiModeStatus};

fn main() -> anyhow::Result<()> {
    // 1. Initialize system logger & event loop
    esp_idf_svc::sys::link_patches();
    EspLogger::initialize_default();
    log::set_max_level(log::LevelFilter::Info);
    println!("");
    println!("  3.98\" 4-Color E-Ink Smart Display (768x552)     ");
    println!("  Target: ESP32-C3 SuperMini | BWRY 4-Color Mode  ");
    println!("");
    info!("[SYSTEM] Booting EPD smart firmware...");

    let peripherals = Peripherals::take()?;

    let sys_loop = EspSystemEventLoop::take()?;
    let nvs_default = EspDefaultNvsPartition::take()?;

    // 2. Load persistent configuration from NVS
    let config_mgr = ConfigManager::new(nvs_default.clone())?;
    let app_config = config_mgr.load();
    let app_config = Arc::new(Mutex::new(app_config));
    let config_mgr = Arc::new(Mutex::new(config_mgr));

    // 3. Initialize hardware SPI and GPIO pins for EPD:
    //    SCK = GPIO 4, MOSI = GPIO 6, CS = GPIO 7, DC = GPIO 1, RST = GPIO 2, BUSY = GPIO 10
    info!("[INIT] Configuring SPI and EPD control GPIO pins...");
    let spi_driver = SpiDriver::new(
        peripherals.spi2,
        peripherals.pins.gpio4, // SCK
        peripherals.pins.gpio6, // MOSI
        None::<esp_idf_hal::gpio::AnyIOPin>,
        &SpiDriverConfig::default(),
    )?;

    let spi_config = SpiConfig::default().baudrate(esp_idf_hal::units::Hertz(8_000_000));
    let spi_device = SpiDeviceDriver::new(spi_driver, None::<esp_idf_hal::gpio::AnyOutputPin>, &spi_config)?;

    let cs = PinDriver::output(peripherals.pins.gpio7)?;
    let dc = PinDriver::output(peripherals.pins.gpio1)?;
    let rst = PinDriver::output(peripherals.pins.gpio2)?;
    let busy = PinDriver::input(peripherals.pins.gpio10, Pull::Up)?;

    let epd = EpdDriver::new(spi_device, cs, dc, rst, busy, PanelVersion::A0);
    let mut fb = Framebuffer::new();

    // Initialize Chinese font MMU mapping from 'font' / 'storage' partition
    crate::display::font::init_chinese_font();

    // Initialize SPIFFS filesystem on 'storage' partition (1.6MB for presets and user assets)
    crate::storage::init_spiffs();

    let (wireless_mode, _ble_enabled) = {
        let cfg = app_config.lock().unwrap();
        (cfg.wireless_mode.clone(), cfg.ble_enabled)
    };

    // 4 & 5. Initialize WiFi & Web Server (unless wireless_mode is 'ble_only')
    let (ip_addr, is_ap, ap_name, _web_server) = if wireless_mode == "ble_only" {
        println!("[WIFI] Wireless mode is 'ble_only': WiFi subsystem skipped to maximize BLE stability & battery.");
        ("0.0.0.0".to_string(), false, "EPD-Display-Setup".to_string(), None)
    } else {
        println!("[INIT] Initializing WiFi subsystem...");
        let (ip, ap, ap_ssid) = match WifiManager::new(peripherals.modem, sys_loop, Some(nvs_default)) {
            Ok(mut wifi_mgr) => {
                let wifi_status = wifi_mgr.start(&app_config.lock().unwrap());
                let res = match &wifi_status {
                    Ok(WifiModeStatus::StationConnected(ip)) => {
                        println!("[WIFI] Connected to Station. IP: {}", ip);
                        (ip.clone(), false, "".to_string())
                    }
                    Ok(WifiModeStatus::AccessPointActive(ap_ssid)) => {
                        println!("[WIFI] SoftAP Active: {} (IP: 192.168.4.1)", ap_ssid);
                        ("192.168.4.1".to_string(), true, ap_ssid.clone())
                    }
                    Err(e) => {
                        println!("[WIFI] Startup failed: {:?}. Fallback to AP mode.", e);
                        ("192.168.4.1".to_string(), true, "EPD-Display-Setup".to_string())
                    }
                };
                // Leak wifi_mgr to guarantee Wi-Fi driver & captive DNS never drop/stop!
                Box::leak(Box::new(wifi_mgr));
                res
            }
            Err(e) => {
                println!("[WIFI] WARNING: WifiManager::new failed: {:?}. Wi-Fi skipped, BLE active.", e);
                ("0.0.0.0".to_string(), false, "".to_string())
            }
        };

        // 4b. Initialize Bluetooth BLE 5.0 NimBLE subsystem & RF Coexistence (early to guarantee contiguous RAM)
        {
            let (w_mode, b_name, b_enabled) = {
                let cfg = app_config.lock().unwrap();
                (cfg.wireless_mode.clone(), cfg.ble_device_name.clone(), cfg.ble_enabled)
            };
            crate::ble::BleManager::global().init(
                &w_mode,
                &b_name,
                b_enabled,
                Some(config_mgr.clone()),
                Some(app_config.clone()),
            );
            crate::ble::BleManager::global().set_ip_info(&ip, ap);
            if !ap && !ip.is_empty() && ip != "0.0.0.0" {
                crate::ble::BleManager::global().on_wifi_configured();
            }
        }

        println!("[INIT] Starting Embedded Web Server & REST API on port 80 (IP: {})...", ip);
        let srv = match WebServer::start(config_mgr.clone(), app_config.clone(), ip.clone(), ap) {
            Ok(s) => {
                println!("[HTTP] Web Server successfully running on port 80!");
                Some(s)
            }
            Err(e) => {
                println!("[HTTP] WARNING: WebServer failed: {:?}. Continuing...", e);
                None
            }
        };
        // Skip dedicated mDNS thread to conserve 5.5KB SRAM for Wi-Fi and BLE coexistence
        // Users navigate directly via http://<ip_addr>/ or PWA
        /*
        if !ap && ip != "0.0.0.0" {
            if let Ok(ipv4) = ip.parse::<std::net::Ipv4Addr>() {
                crate::wifi::mdns::start_mdns("epd-display", ipv4);
            }
        }
        */

        (ip, ap, ap_ssid, srv)
    };

    // 6. Start MQTT client (in Station mode only, and not in ble_only mode)
    if !is_ap && wireless_mode != "ble_only" {
        let mac_str = {
            let mut mac = [0u8; 6];
            unsafe { esp_idf_svc::sys::esp_efuse_mac_get_default(mac.as_mut_ptr()) };
            format!("{:02X}:{:02X}:{:02X}:{:02X}:{:02X}:{:02X}", mac[0], mac[1], mac[2], mac[3], mac[4], mac[5])
        };
        let mac_suffix = {
            let mut mac = [0u8; 6];
            unsafe { esp_idf_svc::sys::esp_efuse_mac_get_default(mac.as_mut_ptr()) };
            format!("{:02x}{:02x}", mac[4], mac[5])
        };
        crate::mqtt::start_mqtt_service(
            config_mgr.clone(),
            app_config.clone(),
            ip_addr.clone(),
            mac_str,
            mac_suffix,
        );
    }

    // 8. Render Initial Screen into Framebuffer
    // E-ink is bistable: screen physically retains the image indefinitely without power!
    // Never refresh on boot unless:
    // a) Chip booted from brownout (undervoltage detected: must overlay low battery warning!)
    // b) Unconfigured (first boot)
    // c) Unconfigured (first boot): show Welcome Screen with project repo & dual Wi-Fi/BLE guides
    // d) In SoftAP mode (configured previously, but fell back to AP)
    let is_brownout = crate::power::PowerManager::check_undervoltage_on_boot();
    let is_configured = config_mgr.lock().unwrap().is_configured();
    crate::display::set_unconfigured(!is_configured);
    println!("[CONFIG] Device is_configured: {}", is_configured);

    let saved_screen_crc = app_config.lock().unwrap().last_screen_crc;
    let ble_name = app_config.lock().unwrap().ble_device_name.clone();

    let initial_check_crc = if is_brownout {
        println!("⚠️ [DISPLAY] BROWNOUT DETECTED! Overlaying low battery warning card on current screen...");
        crate::display::overlay_low_battery_warning(&mut fb);
        true
    } else if !is_configured {
        println!("[DISPLAY] Unconfigured device detected: rendering Welcome Screen with dual Wi-Fi/BLE guidance...");
        crate::modes::provisioning::render_welcome_screen(&mut fb, &ap_name, "192.168.4.1", &ble_name);
        true
    } else if is_ap {
        println!("[DISPLAY] Rendering SoftAP Chinese guidance screen (SSID: {})...", ap_name);
        crate::modes::provisioning::render_waiting_setup(&mut fb, &ap_name, "192.168.4.1");
        true
    } else {
        let mut ctx = ModeContext::default();
        ctx.ip_str = ip_addr.clone();
        ctx.wifi_ssid = app_config.lock().unwrap().wifi_ssid.clone();

        if saved_screen_crc == 0 {
            // Wi-Fi provisioned / first boot: render clean modern MicroPython demo layout with WebUI URL
            println!("[DISPLAY] Wi-Fi provisioned / First boot: rendering initial demo layout...");
            crate::modes::demo_layout::render_demo_layout(&mut fb, &ctx);
            true
        } else {
            // Normal boot / power restored: preserve bistable e-ink image with ZERO flicker!
            println!("[DISPLAY] Normal boot: e-ink bistable image preserved (CRC: 0x{:08X}). ZERO flicker startup!", saved_screen_crc);
            false
        }
    };

    // 9. Run Display Event Loop on main task (0 extra threads, 0 bytes heap allocated)
    println!("[SYSTEM] Initialization complete. All background services operational.");
    println!("[DISPLAY] Entering display event loop on main task (initial_check_crc: {})...", initial_check_crc);
    crate::display::run_display_loop(epd, fb, config_mgr, app_config, ip_addr, initial_check_crc);
}

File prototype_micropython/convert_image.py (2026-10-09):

# 壳 3.98英寸 4色墨水屏 图片取模与转码工具
# 将任意 PNG / JPG 图片转换为 4 色 (黑/白/黄/红) Floyd-Steinberg 误差扩散抖动点阵
# 输出可在 MicroPython 中零内存流式加载的 .raw 二进制文件
# By ZGQ Inc.

import sys
import os
import numpy as np
from PIL import Image, ImageEnhance

def convert_image(input_path, output_raw, target_w=280, target_h=280, contrast=1.25, sharpness=1.5):
    """
    转换图片为 4 色墨水屏点阵
    :param input_path: 输入图片路径
    :param output_raw: 输出 .raw 文件路径
    :param target_w: 目标宽度 (像素, 建议 4 的倍数)
    :param target_h: 目标高度 (像素)
    """
    if target_w % 4 != 0:
        raise ValueError("目标宽度必须为 4 的整数倍！")

    print(f"正在读取图片: {input_path}")
    im = Image.open(input_path).convert('RGB')

    # 适度增强对比度和清晰度，使墨水屏显示效果更通透
    if contrast != 1.0:
        im = ImageEnhance.Contrast(im).enhance(contrast)
    if sharpness != 1.0:
        im = ImageEnhance.Sharpness(im).enhance(sharpness)

    im_resized = im.resize((target_w, target_h), Image.Resampling.LANCZOS)

    # 4 色调色板 (标准 BWRY 调色板)
    # 0: 黑色 (0, 0, 0)
    # 1: 白色 (255, 255, 255)
    # 2: 黄色 (255, 215, 0)
    # 3: 红色 (220, 20, 40)
    palette_colors = [
        (0, 0, 0),
        (255, 255, 255),
        (255, 215, 0),
        (220, 20, 40)
    ]

    palette_img = Image.new('P', (1, 1))
    flat_palette = []
    for c in palette_colors:
        flat_palette.extend(c)
    flat_palette.extend([0] * (768 - len(flat_palette)))
    palette_img.putpalette(flat_palette)

    # Floyd-Steinberg 误差扩散抖动量化
    dithered = im_resized.quantize(palette=palette_img, dither=Image.Dither.FLOYDSTEINBERG)
    pixels = np.array(dithered, dtype=np.uint8)

    # 生成预览 PNG
    preview_path = os.path.splitext(output_raw)[0] + "_preview.png"
    dithered.convert('RGB').save(preview_path)
    print(f"已生成 4 色预览图: {preview_path}")

    # 打包为 MicroPython GS2_HMSB 显存格式:
    # 1 字节容纳 4 个像素: p0 at bits [1:0], p1 at bits [3:2], p2 at bits [5:4], p3 at bits [7:6]
    row_bytes = target_w // 4
    packed_rows = []
    for r in range(target_h):
        row_buf = bytearray(row_bytes)
        for c in range(row_bytes):
            p0 = pixels[r, c*4 + 0]
            p1 = pixels[r, c*4 + 1]
            p2 = pixels[r, c*4 + 2]
            p3 = pixels[r, c*4 + 3]
            row_buf[c] = (p3 << 6) | (p2 << 4) | (p1 << 2) | p0
        packed_rows.append(row_buf)

    raw_data = b''.join(packed_rows)
    with open(output_raw, 'wb') as f:
        f.write(raw_data)

    print(f"已生成点阵文件: {output_raw} (大小: {len(raw_data)} 字节, {target_w}x{target_h})")

if __name__ == '__main__':
    if len(sys.argv) < 3:
        print("用法: python convert_image.py <输入图片> <输出raw文件> [宽=280] [高=280]")
        print("示例: python convert_image.py my_avatar.png avatar.raw 280 280")
    else:
        in_file = sys.argv[1]
        out_file = sys.argv[2]
        w = int(sys.argv[3]) if len(sys.argv) > 3 else 280
        h = int(sys.argv[4]) if len(sys.argv) > 4 else 280
        convert_image(in_file, out_file, w, h)

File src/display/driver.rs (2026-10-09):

// src/display/driver.rs — SE0398NZ07-FNG-A0/A1 4-Color E-Ink Hardware Driver

use std::thread::sleep;
use std::time::{Duration, Instant};

use esp_idf_hal::delay::FreeRtos;
use esp_idf_hal::gpio::{Input, Output, PinDriver};
use esp_idf_hal::spi::{SpiDeviceDriver, SpiDriver};
use log::{info, warn};

use crate::display::framebuffer::{BYTES_PER_ROW, EPD_HEIGHT, Framebuffer};

pub enum PanelVersion {
    A0,
    A1,
}

pub struct EpdDriver<'d> {
    spi: SpiDeviceDriver<'d, SpiDriver<'d>>,
    cs: PinDriver<'d, Output>,
    dc: PinDriver<'d, Output>,
    rst: PinDriver<'d, Output>,
    busy: PinDriver<'d, Input>,
    panel_version: PanelVersion,
    pub flip_180: bool,
}

impl<'d> EpdDriver<'d> {
    pub fn new(
        spi: SpiDeviceDriver<'d, SpiDriver<'d>>,
        cs: PinDriver<'d, Output>,
        dc: PinDriver<'d, Output>,
        rst: PinDriver<'d, Output>,
        busy: PinDriver<'d, Input>,
        panel_version: PanelVersion,
    ) -> Self {
        Self {
            spi,
            cs,
            dc,
            rst,
            busy,
            panel_version,
            flip_180: false,
        }
    }

    #[inline(always)]
    fn send_cmd(&mut self, cmd: u8) -> anyhow::Result<()> {
        self.dc.set_low()?;
        self.cs.set_low()?;
        self.spi.write(&[cmd])?;
        self.cs.set_high()?;
        Ok(())
    }

    #[inline(always)]
    fn send_data(&mut self, data: &[u8]) -> anyhow::Result<()> {
        self.dc.set_high()?;
        self.cs.set_low()?;
        self.spi.write(data)?;
        self.cs.set_high()?;
        Ok(())
    }

    /// Wait for BUSY pin to go HIGH (ready state).
    /// Low = busy refreshing or powering on/off.
    pub fn wait_busy(&self, timeout_ms: u64) -> anyhow::Result<()> {
        let start = Instant::now();
        FreeRtos::delay_ms(20);
        while self.busy.is_low() {
            if start.elapsed().as_millis() > timeout_ms as u128 {
                warn!("[EPD] BUSY timeout after {} ms!", timeout_ms);
                break;
            }
            sleep(Duration::from_millis(50));
        }
        Ok(())
    }

    /// Initializes hardware: Reset pulse, panel configuration, power on.
    pub fn init_hw(&mut self) -> anyhow::Result<()> {
        // 1. Hardware reset pulse
        self.rst.set_low()?;
        FreeRtos::delay_ms(40);
        self.rst.set_high()?;
        FreeRtos::delay_ms(50);
        self.wait_busy(2000)?;
        FreeRtos::delay_ms(30);

        // 2. Panel Setting (PSR 0x00 -> 0x0B)
        self.send_cmd(0x00)?;
        self.send_data(&[0x0B])?;

        // 3. Resolution Setting (TRES 0x61 -> 768 x 600 scan range)
        self.send_cmd(0x61)?;
        self.send_data(&[0x03, 0x00, 0x02, 0x58])?;

        // 4. Power On Boost Circuit (0x04)
        self.send_cmd(0x04)?;
        self.wait_busy(2000)?;

        info!("[EPD] Hardware initialization complete.");
        Ok(())
    }

    /// Flushes the 105,984-byte framebuffer to EPD using interlaced gate scanline mapping,
    /// triggers full physical waveform refresh (15~16s), and powers off boost.
    pub fn display(&mut self, fb: &Framebuffer) -> anyhow::Result<()> {
        info!("[EPD] Starting display transmission and 16s full refresh...");
        self.init_hw()?;

        let mut area_buf = [0x00u8, 0x00, 0x02, 0xFF, 0, 0, 0, 0, 0x01];
        let raw_buf = fb.as_slice();
        let is_a1 = matches!(self.panel_version, PanelVersion::A1);
        let flip_180 = self.flip_180;

        // Transmit 552 scanlines with physical interlacing address conversion
        for s2 in 0..EPD_HEIGHT {
            let row = if flip_180 { 551 - s2 } else { s2 };

            let y: u16 = if is_a1 {
                if s2 <= 299 {
                    (s2 * 2).saturating_sub(599) as u16
                } else {
                    (s2 * 2) as u16
                }
            } else {
                if s2 <= 275 {
                    (s2 * 2) as u16
                } else {
                    (1103 - 2 * s2) as u16
                }
            };

            area_buf[4] = (y >> 8) as u8;
            area_buf[5] = (y & 0xFF) as u8;
            area_buf[6] = (y >> 8) as u8;
            area_buf[7] = (y & 0xFF) as u8;

            // 0x83: Set Partial RAM Area
            self.send_cmd(0x83)?;
            self.send_data(&area_buf)?;

            // 0x10: Write RAM Data (192 bytes / scanline)
            self.send_cmd(0x10)?;
            let start = row * BYTES_PER_ROW;
            self.send_data(&raw_buf[start..start + BYTES_PER_ROW])?;
        }

        // Restore RAM scanning area to default (0..767, 0..599)
        self.send_cmd(0x83)?;
        self.send_data(&[0x00, 0x00, 0x02, 0xFF, 0x00, 0x00, 0x02, 0x57, 0x01])?;

        // Trigger 4-color physical waveform full refresh (0x12, 0x01)
        info!("[EPD] Triggering physical waveform refresh (~15s)...");
        self.send_cmd(0x12)?;
        self.send_data(&[0x01])?;
        self.wait_busy(35000)?;

        // Power off high voltage circuit to protect display from overcharging
        self.send_cmd(0x02)?;
        self.send_data(&[0x00])?;
        self.wait_busy(5000)?;

        info!("[EPD] Refresh successfully completed!");
        Ok(())
    }

    /// Puts the EPD controller into ultra-low-power sleep mode (< 5 uA).
    pub fn sleep(&mut self) -> anyhow::Result<()> {
        self.send_cmd(0x02)?;
        self.send_data(&[0x00])?;
        self.wait_busy(3000)?;

        // Deep sleep entry command (0x07 -> 0xA5)
        self.send_cmd(0x07)?;
        self.send_data(&[0xA5])?;
        FreeRtos::delay_ms(200);

        info!("[EPD] Controller entered deep sleep.");
        Ok(())
    }
}

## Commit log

2026-10-09 fix(ble): robust GATT connection and prevent null device reference error
2026-10-09 feat: support 4-way portrait/landscape adaptive rotation and add bottom lanyard hole to enclosure
    [case_middle.stl, epd_case.scad]
2026-10-09 feat(wireless): add safety confirmations, fix wifi_only reboot, and report IP over BLE
    [main.rs, mod.rs]
2026-10-09 fix(web): resolve preview freeze with zero-heap PackBits RLE and add wireless safety guards
    [mod.rs]
2026-10-10 fix(web): expand max_uri_handlers to 64 to resolve ESP_ERR_HTTPD_HANDLERS_FULL; optimize BLE advertising interval to 50-100ms and restart on disconnect
    [mod.rs]
2026-10-10 fix(web, coexistence): fix dark theme loading, JS syntax error, and enforce RF auto coexistence
    [main.rs, mod.rs]
2026-10-10 feat(storage, presets): 2MB firmware repartition, 1.63MB SPIFFS preset engine, and bidirectional PWA sync
    [partitions.csv]
2026-10-10 fix(web, ble): resolve RF coexistence contention, fix GATT handshake, and add footer credits
    [main.rs, mod.rs]
2026-10-10 fix(ble, web): restore standard BLE in auto mode, remove disruptive wifi stop, and enforce HTTP socket closure
    [mod.rs]
2026-10-10 refactor(pwa, web): decouple heavy studio to PWA with modular css/js, responsive sliding tabs, and slim down on-device console
2026-10-10 feat(pwa): restore all missing features, integrate InkSight open data engines, and optimize Material Web UX
2026-10-10 fix(ble, pwa, web): resolve GATT disconnect, prevent binary offset reset, restore full 18-metric diagnostics and MQTT config, and redesign OC PIC itabag
    [mod.rs]
2026-10-10 fix(ble, web, pwa): resolve GATT disconnect by fixing unsolicited notifications, pass dynamic IP to PWA, and remove quick mode switcher from web console
    [mod.rs]
2026-10-10 fix(presets, ble): store presets in MCU SPIFFS with writing progress, enable internal read push, and resolve hardware sync connectivity
    [mod.rs]
2026-10-10 fix(presets): eliminate signal timeout, read physical MCU storage, and fix preset persistence
    [mod.rs]
2026-10-10 docs: strip debug symbols, provide 1.76MB bin, revamp BOM and build guide with Huawei surplus specs
2026-10-11 fix(web): purge hardcoded private IP, fix Mixed Content/CORS headers, enhance BLE GATT reconnection
    [mod.rs]
2026-10-11 feat(web): 全功能模块与渲染管线深度适配屏幕 4 向旋转朝向 (0°/90°/180°/270°)
    - dither.js: 增加 0°/90°/180°/270° 硬件显存点阵量化打包与逆向解码展示，统一输出物理 768×552 BWRY 2bpp 帧缓冲区
    - canvas.js: 画板自适应 552×768 (竖屏) 与 768×552 (横屏)，旋转切换保持绘图内容无失真
    - itabag.js: 痛卡工坊全要素适配竖屏 (552×768) 与横屏 (768×552)，动态调整立绘、徽章、题字与挂件边框
    - studio.js: 便签与清单备忘工坊自适应竖屏长文本布局与横屏布局
    - scenes.js: 场景工坊 18 套全能场景全量适配横屏 (768×552) 与竖屏 (552×768)，动态自适应网格、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
2026-10-11 fix(itabag): 移除痛卡工坊冗余的局部旋转角度设置
2026-10-11 feat(presets,scenes,canvas): 移除圆头笔、增加场景全黄清屏与单片机Flash一键清空重置功能
2026-10-11 feat(presets): 支持元数据两阶段写入校验、孤儿文件单独删除与一键清理无效数据
2026-10-11 docs(license): 明确 MIT 开源许可规范，消除 All Rights Reserved 歧义并补充作者昵称署名说明
2026-10-11 build(firmware): 编译最新 Rust 裸机固件，剥离生成 epd-firmware.bin 并成功刷入单片机
2026-10-11 fix(web): 提升 HTTPD 最大 URI 路由句柄上限 (48 -> 64) 彻底解决 ESP_ERR_HTTPD_HANDLERS_FULL 导致控制台无法启动的问题
2026-10-11 fix(web,wifi,pwa): 修复PWA参数过滤，重构Web控制台分块流式传输与LwIP套接字内存配额
2026-10-11 fix(web): 修复网页压缩误删URL导致未闭合a标签与全页变蓝问题，恢复PWA动态传参与302重定向
2026-10-11 fix(ble, pwa, doc): 恢复模式切换警告弹窗与当前模式状态读取，修复移动端PWA传参，解决BLE广播控制器活动超限，补充CLI免拆机恢复出厂指南
2026-10-11 fix(pwa, storage): fix preset modal button lock and SPIFFS filename length limit
    - Fix btnConfirmWritePreset remaining disabled on success in promptSavePreset, causing 2nd preset save click to be completely unresponsive without page refresh
    - Add try-finally block and unlock button on modal open and close
    - Shorten preset ID to base36 to strictly satisfy SPIFFS 32-char object path limit (/spiffs/presets/<id>.json)
    - Pass preset ID to hardware in savePresetToDevice to maintain consistent indexing
    - Restore BLE auto_refresh mode upon stream write completion
    - Bump PWA Service Worker cache version to v3.9
2026-10-11 fix(storage, web): fix preset push corruption, prevent heap exhaustion, and eliminate no space ENOSPC errors
    - Implement zero-heap direct framebuffer loading (load_preset_to_framebuffer) to eliminate 106KB heap allocations on ESP32-C3
    - Add self-healing JSON parser (parse_preset_meta) and directory scanning repair to sanitize trailing log pollution from preset JSON files
    - Increase SPIFFS max_files from 2 to 5 to prevent file descriptor exhaustion
    - Write 2bpp bitmap in 4KB chunks with atomic file handle closure and rollback on error to eliminate SPIFFS_ERR_FULL (ENOSPC)
    - Stream preset list and responses in chunked JSON to prevent 8192-byte heap allocation failure and web console crashes
    -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
2026-10-11 perf(web): stream index.html.gz in 1KB chunks to avoid TCP socket send buffer blocking
    - Stream index.html.gz in 1024-byte chunks for '/' and '/app' routes to fit within lwIP TCP send window (SND_BUF)
    - Eliminates 20-second connection stalls and timeouts when refreshing web console in browser
2026-10-12 fix(pwa): 点开预设预览弹窗内的直推按钮复用内部直推API (DeviceManager.pushPreset)
2026-10-12 feat(pwa, web): 实现单片机独立存储预设点阵流式调步拉取与进度条渲染，统一弹窗内部直推链路
2026-10-12 fix(pwa, web, doc): 修复ui.js中modalTitle重复声明导致的UI未定义崩溃，恢复系统模式读取与PNA标头放行，补充espflash免拆机恢复出厂指南
2026-10-12 feat(ntp): 单片机集成阿里云NTP授时与UTC+8时区管理，打通墨水屏实时时钟与状态展示
2026-10-12 feat(presets): 单片机预设点阵流式传输引入零内存PackBits压缩，实现局域网秒级预览与连接保活
2026-10-12 feat(ui): 图片调色工坊支持图片直接拖入，清理场景遥控重复射频控件，将2bpp显存裸流导入导出移入硬件诊断
2026-10-12 fix(dither): 修复误差扩散边缘黑锯齿色偏，图片调色增加平移缩放交互与自适应不遮挡布局
2026-10-12 feat(image-lab): 适配移动端交互，移除画框遮挡浮标，实现四周圆点选择器交互缩放
2026-10-12 feat(itabag): 深度支持二次元与OC角色立绘，增强画布手势平移缩放交互与满幅纯享立牌展示
2026-10-12 feat: add A0/A1 screen panel version switch to web console and PWA
2026-10-12 docs(hardware): add wiring and soldering guide for EPD, ESP32-C3, TP4056 and battery
2026-10-12 docs(hardware): replace ASCII circuit diagrams with modern Mermaid charts
2026-10-12 docs(hardware): align ESP32 and Driver board side-by-side in Mermaid diagram
2026-10-14 feat(ble): add two-way device management, dynamic PIN pairing, NFC key claim, and anti-DoS protection
2026-10-14 fix(ble, web, pwa): 修复Windows下WebBLE断开与GATT句柄冲突，优化NimBLE任务栈与LwIP缓冲，完善Playwright前端认证流程
2026-10-14 fix(web, pwa): 优化局域网控制台连接超时至10秒，重定向Station模式根路径至PWA杜绝LwIP堆缓冲死锁
2026-10-15 fix(web): optimize local console delivery, solve socket starvation & add live NVS stats
2026-10-15 fix(web, ble): 彻底修复单核CPU与TCP缓冲互锁死锁，实现分片流动传输与快速套接字回收，支持NVS真实容量测算
2026-10-15 perf(memory): 落地方案A内存优化，将空闲堆提升至26KB+，实现SoftAP仅在未初始化阶段运行与BLE配对提示
2026-10-15 fix(ble, pwa): 修复已授权设备列表流式传输与NFC钥匙显示，优化GATT并发写入队列与本地缓存
2026-10-17 Fix link to hardware BOM in README
    Updated the link to the hardware BOM document to reflect the new path.
